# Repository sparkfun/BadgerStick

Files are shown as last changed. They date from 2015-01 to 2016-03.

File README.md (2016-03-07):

Interactive Badges
==================
 
 
 
 [*SparkFun BadgerHack *](https://learn.sparkfun.com/tutorials/badgerhack)
 
 These badges were designed as a soldering demo for the SparkFun booths at Maker Faire. 
 They were designed to teach the basics of PTH soldering, as well as to provide users with an Arduino platform they could take home and hack.
 
Please view the [BadgerHack tutorial](https://learn.sparkfun.com/tutorials/badgerhack) for more information on updating the firmware, and further experiments with your badge. 
 
 Repository Contents
-------------------

* **/badgerstick/avr** - Board definition files for Arduino.
* **/Documentation** - SoftwareSerial Baud Rate table
* **/Firmware** - Default firmware that ships on the BadgerStick
* **/Hardware** - All Eagle design files (.brd, .sch)
* **/Production** - Test bed files and production panel files

Documentation
--------------
* **[Library](https://github.com/sparkfun/SparkFun_LED_Array_8x7_Arduino_Library)** - Arduino library for the BadgerStick.
* **[Hookup Guide](https://learn.sparkfun.com/tutorials/badgerhack)** - Basic hookup guide for the BadgerStick. 
* **[SparkFun Fritzing repo](https://github.com/sparkfun/Fritzing_Parts)** - Fritzing diagrams for SparkFun products.
* **[SparkFun 3D Model repo](https://github.com/sparkfun/3D_Models)** - 3D models of SparkFun products. 
* **[SparkFun Graphical Datasheets](https://github.com/sparkfun/Graphical_Datasheets)** -Graphical Datasheets for various SparkFun products.

License Information
-------------------

This product is _**open source**_! 

Please review the LICENSE.md file for license information. 

If you have any questions or concerns on licensing, please contact techsupport@sparkfun.com.

Distributed as-is; no warranty is given.

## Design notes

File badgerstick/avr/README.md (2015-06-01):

Custom bootloader and board definition file

Version
-------

**v0.2**

Known Issues
------------

Getting Started
---------------

I want to upload Arduino sketches to my BadgerStick (which already has the bootloader).

* Copy the badgerstick directory to <Arduino folder>/hardware/
* Open the Arduino program
* BadgerStick should appear under Tools -> Board

I want to compile the BadgerStick bootloader.

* Copy ATmegaBOOT_168.c and the Makefile located in bootloaders/atmega to <Arduino folder>/hardware/arduino/bootloaders/atmega
* Open a command terminal
* Navigate to <Arduino folder>/hardware/arduino/bootloaders/atmega
* Enter the command: make

I want to burn the bootloader onto the BadgerStick.

* If you did not compile the bootloader, copy the ATmegaBOOT_168_atmega328_pro_4MHz.hex file in bootloaders/atmega to <Arduino folder>/hardware/arduino/bootloaders/atmega
* Follow the instructions at [http://arduino.cc/en/Tutorial/ArduinoISP](http://arduino.cc/en/Tutorial/ArduinoISP) to use an Arduino as a programmer for the BadgerStick
* Select "BadgerStick (3.3V, 4MHz)" when instructed to select the board "on which you want to burn the bootloader"
* Use the Tools -> Burn Bootloader option
* Wait for the bootloader to finish burning (you will get a notification in the Arduino program)

What Did You Do?
----------------

To create a custom board for the Arduino program, we created a new directory with hardware definitions.

To create a custom bootloader, we changed a few lines of code in ATmegaBOOT_168.c under "// Fix the EEWE bit definition..." in order to fix a compile error (EEPE not defined). We also changed the OPTIMIZE setting to -Os to reduce the size of the bootloader file. Finally, we added a new Make target under "# Added 4MHz version of the 328P" with new fuse settings to allow for lower voltage and 4MHz operation.

Version History
---------------

**v0.2**

* Created separate hardware directory to support Arduino IDE v1.6.3
* Changed upload speed to 250000

**v0.1**

* Initial prototype
* 4MHz with 1.8V brown-out detection Arduino bootloader created for ATmega 328P
* Custom board definition added to boards.txt for the BadgerStick

License
-------

All Arduino code is release under the Creative Commons Attribution Share-Alike license. For more information, see [http://arduino.cc/en/Main/FAQ](http://arduino.cc/en/Main/FAQ).

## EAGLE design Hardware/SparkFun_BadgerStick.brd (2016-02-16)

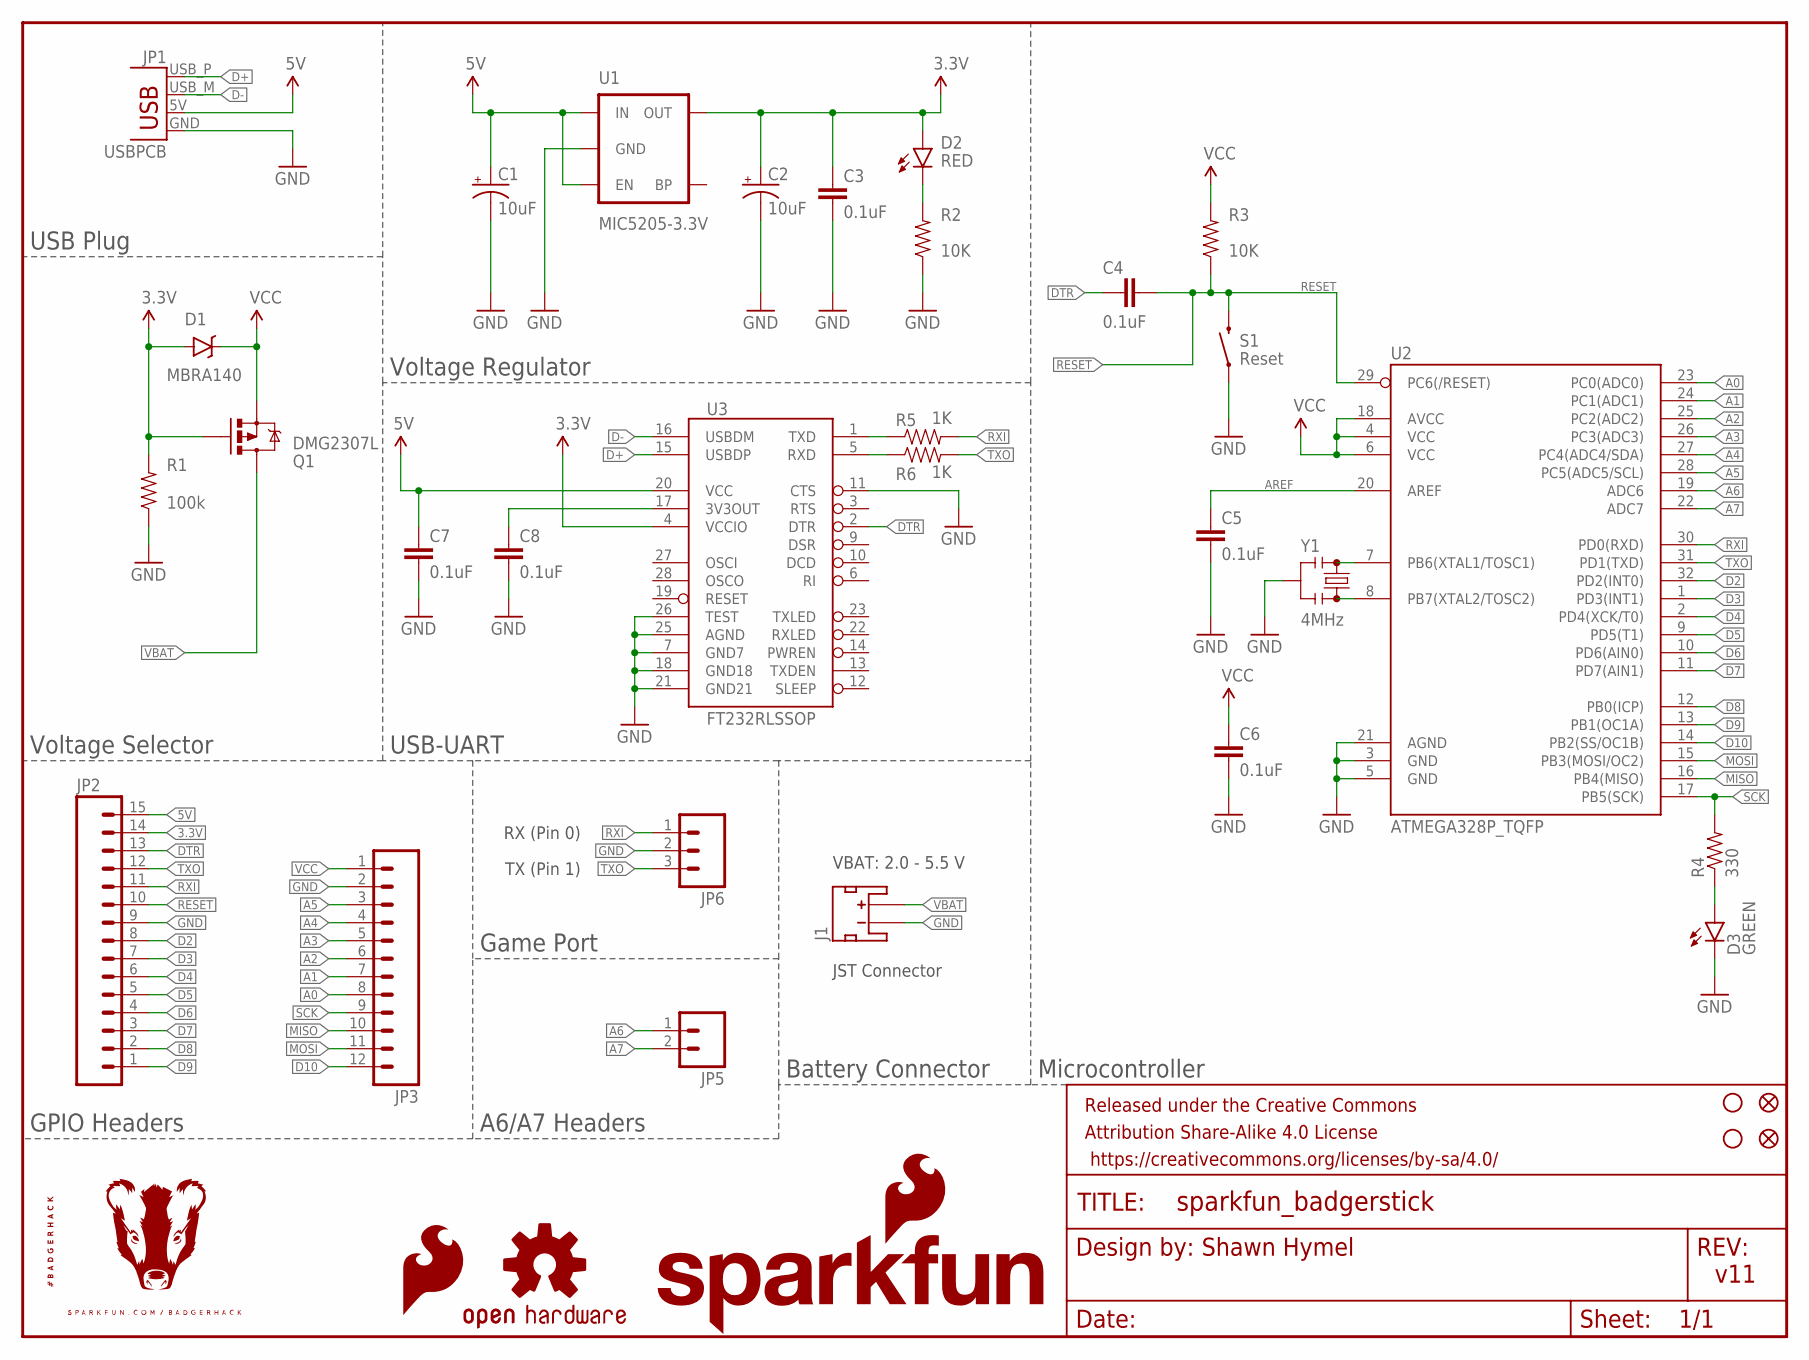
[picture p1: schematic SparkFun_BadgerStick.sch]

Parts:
C1, C2: 10uF; EIA3216
C3, C4, C5, C6, C7, C8: 0.1uF; 0603-CAP
D1: MBRA140; SMA-DIODE
D2: RED; LED-0603
D3: GREEN; LED-0603
FID1, FID2: FIDUCIAL1X2; FIDUCIAL-1X2
FRAME1: FRAME-LETTER; CREATIVE_COMMONS
J1: JST_2MM_MALE; JST-2-SMD
JP1: USBPCB; USB-A-PCB
JP2: M15LOCK_NO_SILK; 1X15_LOCK_NO_SILK
JP3: M12LOCK_NO_SILK; 1X12_LOCK_NO_SILK
JP5: M021X02_NO_SILK; 1X02_NO_SILK
JP6: M03LOCK Female; 1X03_LOCK_NO_SILK
LOGO1: SFE_LOGO_FLAME.1_INCH; SFE_LOGO_FLAME_.1
LOGO2: OSHW-LOGOS; OSHW-LOGO-S
Q1: DMG2307L; SOT23-3
R1: 100k; 0603-RES
R2, R3: 10K; 0603-RES
R4: 330; 0603-RES
R5, R6: 1K; 0603-RES
S1: SWITCH-MOMENTARY-2SMD-REDUNDANT; TACTILE-SWITCH-SMD
STANDOFF1, STANDOFF2: STAND-OFF
U1: MIC5205-3.3V; SOT23-5
U2: ATMEGA328P_TQFP; TQFP32-08
U3: FT232RLSSOP; SSOP28DB
U$1: SFE_LOGO_NAME_FLAME.1_INCH; SFE_LOGO_NAME_FLAME_.1
U$2: BADGERHACK_LOGODUMMY; DUMMY
Y1: 4MHz; RESONATOR-SMD_MED

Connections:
3.3V: C2.A (+), C3.1, D1.A, D2.A, JP2.14, Q1.1 (G), R1.2, U1.5 (OUT), U3.4 (VCCIO)
5V: C1.A (+), C7.1, JP1.5V (VBUS), JP2.15, U1.1 (IN), U1.3 (EN), U3.20 (VCC)
A0: JP3.8, U2.23 (PC0(ADC0))
A1: JP3.7, U2.24 (PC1(ADC1))
A2: JP3.6, U2.25 (PC2(ADC2))
A3: JP3.5, U2.26 (PC3(ADC3))
A4: JP3.4, U2.27 (PC4(ADC4/SDA))
A5: JP3.3, U2.28 (PC5(ADC5/SCL))
A6: JP5.1, U2.19 (ADC6)
A7: JP5.2, U2.22 (ADC7)
AREF: C5.1, U2.20 (AREF)
D2: JP2.8, U2.32 (PD2(INT0))
D3: JP2.7, U2.1 (PD3(INT1))
D4: JP2.6, U2.2 (PD4(XCK/T0))
D5: JP2.5, U2.9 (PD5(T1))
D6: JP2.4, U2.10 (PD6(AIN0))
D7: JP2.3, U2.11 (PD7(AIN1))
D8: JP2.2, U2.12 (PB0(ICP))
D9: JP2.1, U2.13 (PB1(OC1A))
D10: JP3.12, U2.14 (PB2(SS/OC1B))
D+: JP1.USB_P (D+), U3.15 (USBDP)
D-: JP1.USB_M (D-), U3.16 (USBDM)
DTR: C4.1, JP2.13, U3.2 (DTR)
GND: C1.C (-), C2.C (-), C3.2, C5.2, C6.2, C7.2, C8.2, D3.C, J1.1 (-), JP1.GND, JP2.9, JP3.2, JP6.2, R1.1, R2.1, S1.1, S1.2 (1), U1.2 (GND), U2.3 (GND), U2.5 (GND), U2.21 (AGND), U3.7 (GND7), U3.11 (CTS), U3.18 (GND18), U3.21 (GND21), U3.25 (AGND), U3.26 (TEST), Y1.2
MISO: JP3.10, U2.16 (PB4(MISO))
MOSI: JP3.11, U2.15 (PB3(MOSI/OC2))
unnamed: D3.A, R4.1
unnamed: C8.1, U3.17 (3V3OUT)
unnamed: R5.1, U3.1 (TXD)
unnamed: D2.C, R2.2
unnamed: U2.7 (PB6(XTAL1/TOSC1)), Y1.1
unnamed: U2.8 (PB7(XTAL2/TOSC2)), Y1.3
unnamed: R6.1, U3.5 (RXD)
RESET: C4.2, JP2.10, R3.1, S1.3 (2), S1.4 (2), U2.29 (PC6(/RESET))
RXI: JP2.11, JP6.1, R5.2, U2.30 (PD0(RXD))
SCK: JP3.9, R4.2, U2.17 (PB5(SCK))
TXO: JP2.12, JP6.3, R6.2, U2.31 (PD1(TXD))
VBAT: J1.2 (+), Q1.3 (D)
VCC: C6.1, D1.C, JP3.1, Q1.2 (S), R3.2, U2.4 (VCC), U2.6 (VCC), U2.18 (AVCC)

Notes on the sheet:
RX (Pin 0)
TX (Pin 1)
USB Plug
Voltage Selector
GPIO Headers
A6/A7 Headers
Game Port
USB-UART
Voltage Regulator
Microcontroller
Battery Connector
VBAT: 2.0 - 5.5 V
JST Connector

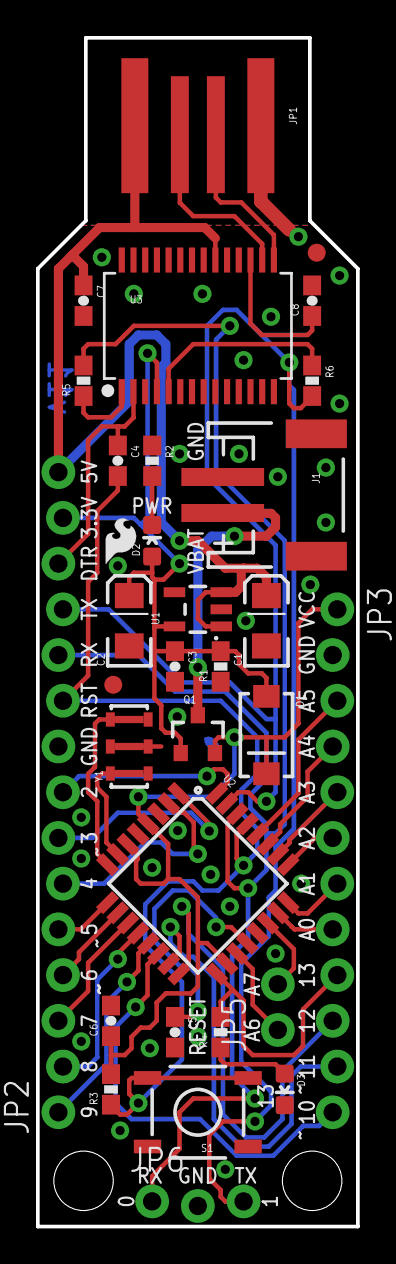
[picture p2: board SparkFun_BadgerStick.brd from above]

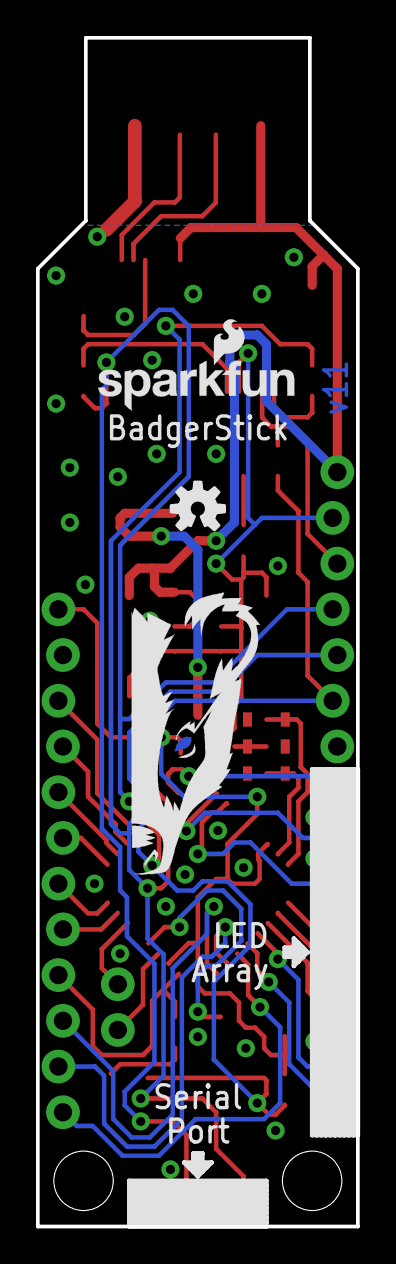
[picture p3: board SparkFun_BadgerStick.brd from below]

Board: 2 copper layers, 17.8 x 66.0 mm, 39 parts (3 on the bottom side), 39 nets.

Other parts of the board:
U$3: HALF_BADGER

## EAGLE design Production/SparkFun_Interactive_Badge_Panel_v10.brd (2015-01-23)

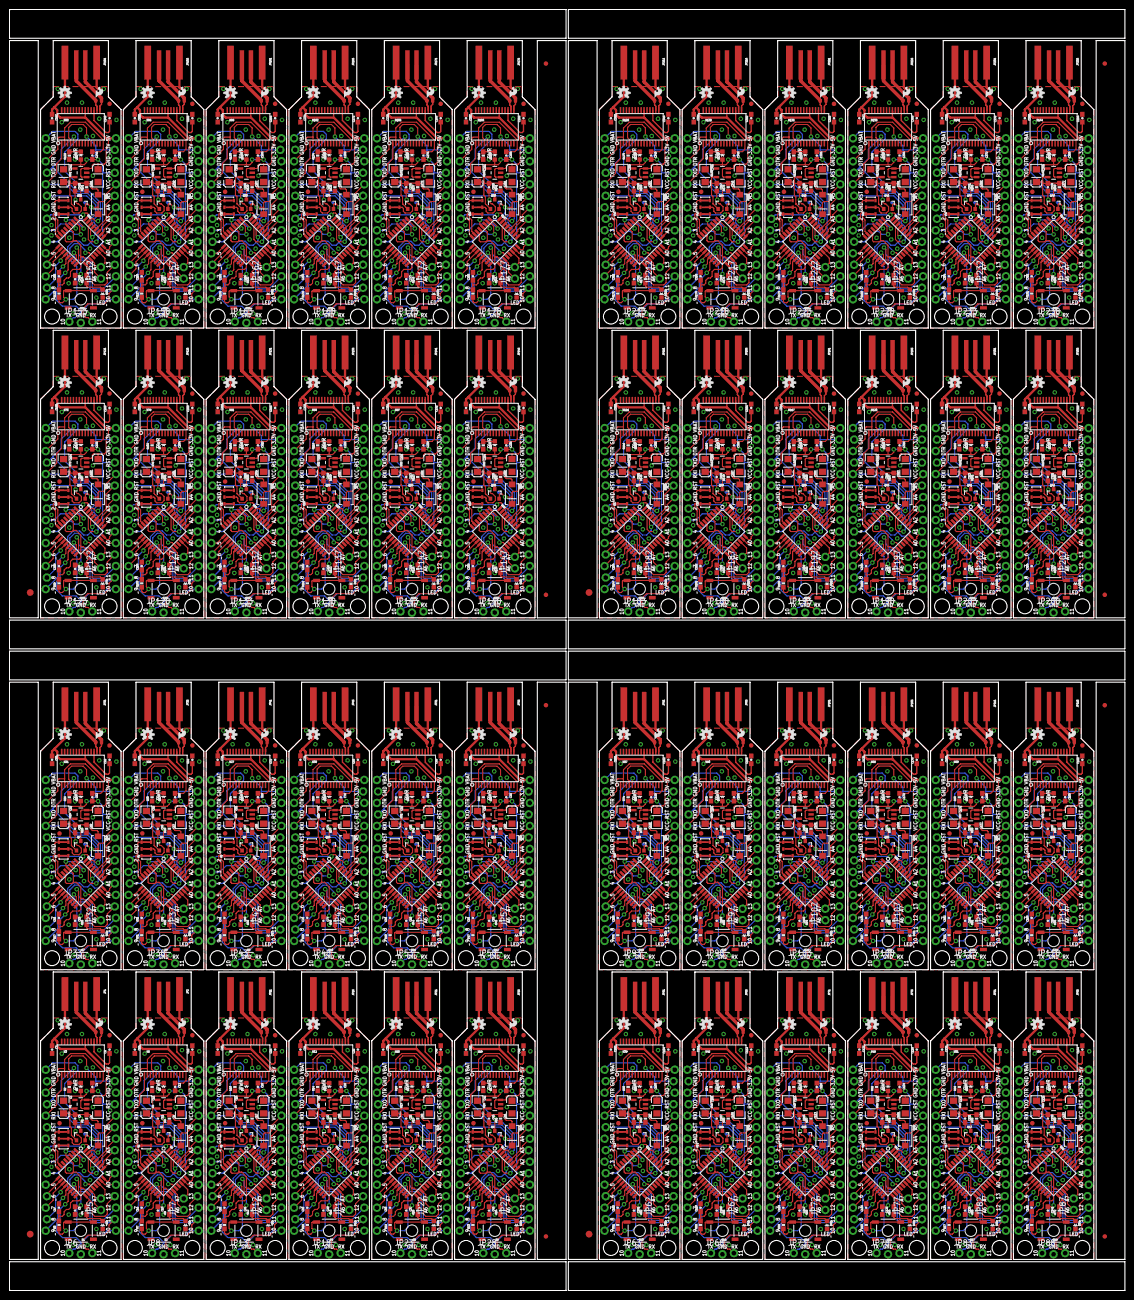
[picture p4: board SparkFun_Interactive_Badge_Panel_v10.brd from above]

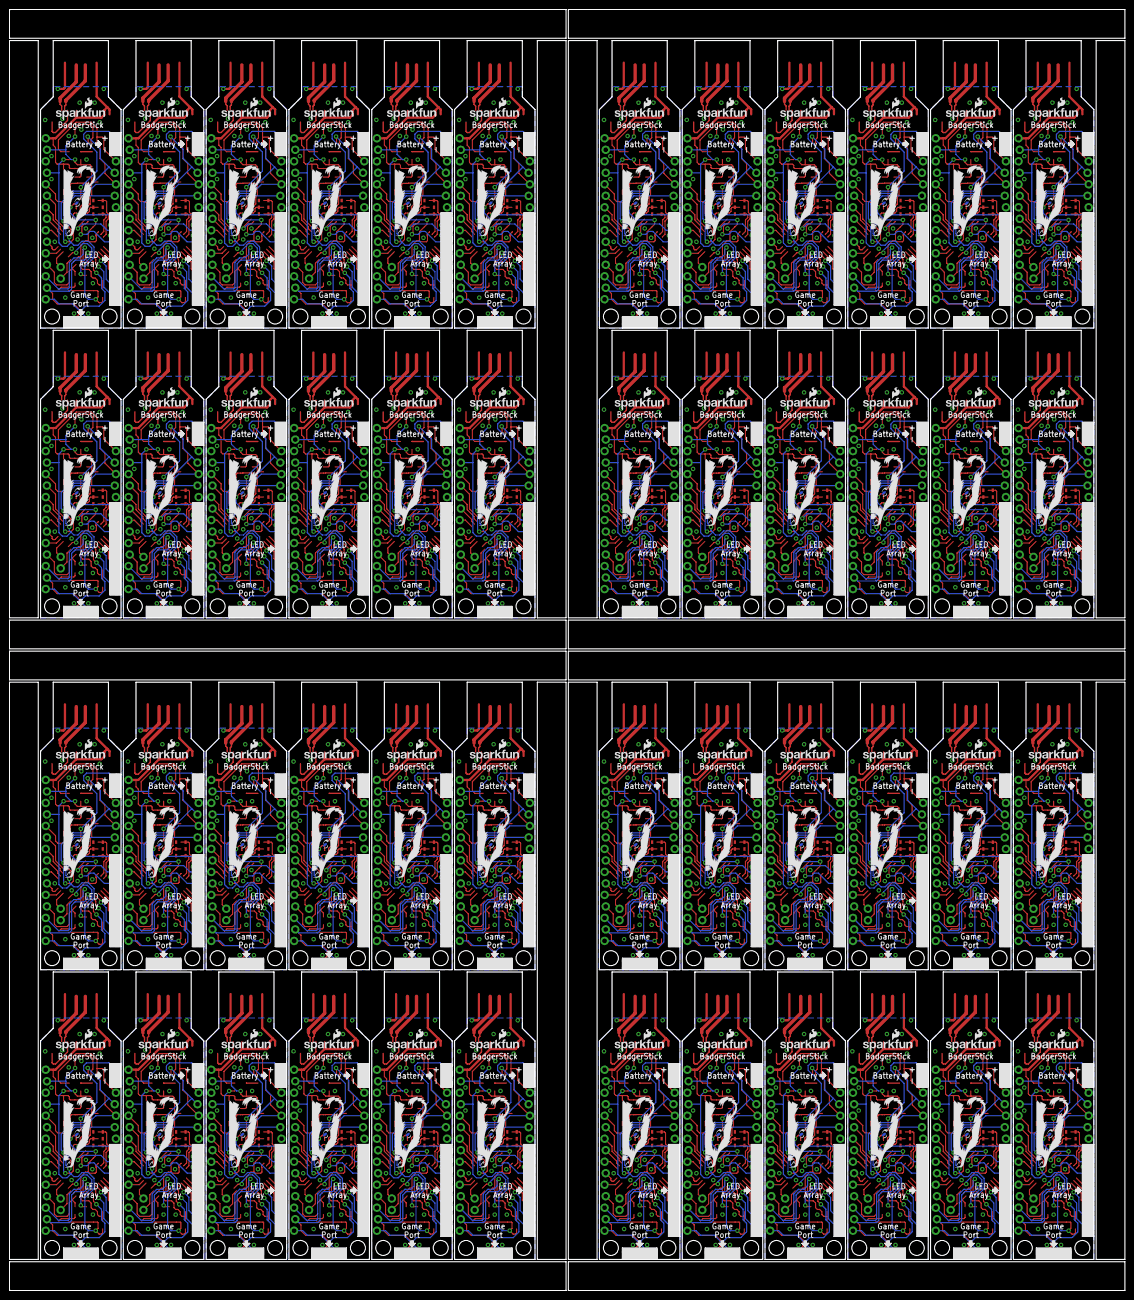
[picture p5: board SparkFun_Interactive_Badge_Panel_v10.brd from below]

Board: 2 copper layers, 246.4 x 283.0 mm, 1644 parts (96 on the bottom side), 1776 nets.

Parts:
C1, C2, C9, C10, C17, C18, C25, C26, C33, C34, C41, C42, C49, C50, C57, C58, C65, C66, C73, C74, C81, C82, C89, C90, C97, C98, C105, C106, C113, C114, C121, C122, C129, C130, C137, C138, C145, C146, C153, C154, C161, C162, C169, C170, C177, C178, C185, C186, C193, C194, C201, C202, C209, C210, C217, C218, C225, C226, C233, C234, C241, C242, C249, C250, C257, C258, C265, C266, C273, C274, C281, C282, C289, C290, C297, C298, C305, C306, C313, C314, C321, C322, C329, C330, C337, C338, C345, C346, C353, C354, C361, C362, C369, C370, C377, C378: 10uF; EIA3216
C3, C4, C5, C6, C7, C8, C11, C12, C13, C14, C15, C16, C19, C20, C21, C22, C23, C24, C27, C28, C29, C30, C31, C32, C35, C36, C37, C38, C39, C40, C43, C44, C45, C46, C47, C48, C51, C52, C53, C54, C55, C56, C59, C60, C61, C62, C63, C64, C67, C68, C69, C70, C71, C72, C75, C76, C77, C78, C79, C80, C83, C84, C85, C86, C87, C88, C91, C92, C93, C94, C95, C96, C99, C100, C101, C102, C103, C104, C107, C108, C109, C110, C111, C112, C115, C116, C117, C118, C119, C120, C123, C124, C125, C126, C127, C128, C131, C132, C133, C134, C135, C136, C139, C140, C141, C142, C143, C144, C147, C148, C149, C150, C151, C152, C155, C156, C157, C158, C159, C160, C163, C164, C165, C166, C167, C168, C171, C172, C173, C174, C175, C176, C179, C180, C181, C182, C183, C184, C187, C188, C189, C190, C191, C192, C195, C196, C197, C198, C199, C200, C203, C204, C205, C206, C207, C208, C211, C212, C213, C214, C215, C216, C219, C220, C221, C222, C223, C224, C227, C228, C229, C230, C231, C232, C235, C236, C237, C238, C239, C240, C243, C244, C245, C246, C247, C248, C251, C252, C253, C254, C255, C256, C259, C260, C261, C262, C263, C264, C267, C268, C269, C270, C271, C272, C275, C276, C277, C278, C279, C280, C283, C284, C285, C286, C287, C288, C291, C292, C293, C294, C295, C296, C299, C300, C301, C302, C303, C304, C307, C308, C309, C310, C311, C312, C315, C316, C317, C318, C319, C320, C323, C324, C325, C326, C327, C328, C331, C332, C333, C334, C335, C336, C339, C340, C341, C342, C343, C344, C347, C348, C349, C350, C351, C352, C355, C356, C357, C358, C359, C360, C363, C364, C365, C366, C367, C368, C371, C372, C373, C374, C375, C376, C379, C380, C381, C382, C383, C384: 0.1uF; 0603-CAP
D1, D4, D7, D10, D13, D16, D19, D22, D25, D28, D31, D34, D37, D40, D43, D46, D49, D52, D55, D58, D61, D64, D67, D70, D73, D76, D79, D82, D85, D88, D91, D94, D97, D100, D103, D106, D109, D112, D115, D118, D121, D124, D127, D130, D133, D136, D139, D142: MBRA140; SMA-DIODE
D2, D5, D8, D11, D14, D17, D20, D23, D26, D29, D32, D35, D38, D41, D44, D47, D50, D53, D56, D59, D62, D65, D68, D71, D74, D77, D80, D83, D86, D89, D92, D95, D98, D101, D104, D107, D110, D113, D116, D119, D122, D125, D128, D131, D134, D137, D140, D143: RED; LED-0603
D3, D6, D9, D12, D15, D18, D21, D24, D27, D30, D33, D36, D39, D42, D45, D48, D51, D54, D57, D60, D63, D66, D69, D72, D75, D78, D81, D84, D87, D90, D93, D96, D99, D102, D105, D108, D111, D114, D117, D120, D123, D126, D129, D132, D135, D138, D141, D144: GREEN; LED-0603
E$1, E$6, E$9, E$12: FIDUCIAL-1.5X3
E$2, E$3, E$4, E$5, E$7, E$8, E$10, E$11: FIDUCIAL-1X2
FID1, FID2, FID3, FID4, FID5, FID6, FID7, FID8, FID9, FID10, FID11, FID12, FID13, FID14, FID15, FID16, FID17, FID18, FID19, FID20, FID21, FID22, FID23, FID24, FID25, FID26, FID27, FID28, FID29, FID30, FID31, FID32, FID33, FID34, FID35, FID36, FID37, FID38, FID39, FID40, FID41, FID42, FID43, FID44, FID45, FID46, FID47, FID48, FID49, FID50, FID51, FID52, FID53, FID54, FID55, FID56, FID57, FID58, FID59, FID60, FID61, FID62, FID63, FID64, FID65, FID66, FID67, FID68, FID69, FID70, FID71, FID72, FID73, FID74, FID75, FID76, FID77, FID78, FID79, FID80, FID81, FID82, FID83, FID84, FID85, FID86, FID87, FID88, FID89, FID90, FID91, FID92, FID93, FID94, FID95, FID96: FIDUCIAL1X2; FIDUCIAL-1X2
JP1, JP2, JP11, JP16, JP21, JP26, JP31, JP36, JP41, JP46, JP51, JP56, JP61, JP66, JP71, JP76, JP81, JP86, JP91, JP96, JP101, JP106, JP111, JP116, JP121, JP126, JP131, JP136, JP141, JP146, JP151, JP156, JP161, JP166, JP171, JP176, JP181, JP186, JP191, JP196, JP201, JP206, JP211, JP216, JP221, JP226, JP231, JP236: USBPCB; USB-A-PCB
JP3, JP4, JP9, JP10, JP14, JP15, JP19, JP20, JP24, JP25, JP29, JP30, JP34, JP35, JP39, JP40, JP44, JP45, JP49, JP50, JP54, JP55, JP59, JP60, JP64, JP65, JP69, JP70, JP74, JP75, JP79, JP80, JP84, JP85, JP89, JP90, JP94, JP95, JP99, JP100, JP104, JP105, JP109, JP110, JP114, JP115, JP119, JP120, JP124, JP125, JP129, JP130, JP134, JP135, JP139, JP140, JP144, JP145, JP149, JP150, JP154, JP155, JP159, JP160, JP164, JP165, JP169, JP170, JP174, JP175, JP179, JP180, JP184, JP185, JP189, JP190, JP194, JP195, JP199, JP200, JP204, JP205, JP209, JP210, JP214, JP215, JP219, JP220, JP224, JP225, JP229, JP230, JP234, JP235, JP239, JP240: M15LOCK_NO_SILK; 1X15_LOCK_NO_SILK
JP5, JP7, JP12, JP17, JP22, JP27, JP32, JP37, JP42, JP47, JP52, JP57, JP62, JP67, JP72, JP77, JP82, JP87, JP92, JP97, JP102, JP107, JP112, JP117, JP122, JP127, JP132, JP137, JP142, JP147, JP152, JP157, JP162, JP167, JP172, JP177, JP182, JP187, JP192, JP197, JP202, JP207, JP212, JP217, JP222, JP227, JP232, JP237: M021X02_NO_SILK; 1X02_NO_SILK
JP6, JP8, JP13, JP18, JP23, JP28, JP33, JP38, JP43, JP48, JP53, JP58, JP63, JP68, JP73, JP78, JP83, JP88, JP93, JP98, JP103, JP108, JP113, JP118, JP123, JP128, JP133, JP138, JP143, JP148, JP153, JP158, JP163, JP168, JP173, JP178, JP183, JP188, JP193, JP198, JP203, JP208, JP213, JP218, JP223, JP228, JP233, JP238: M03LOCK Female; 1X03_LOCK_NO_SILK
LOGO1, LOGO3, LOGO5, LOGO7, LOGO9, LOGO11, LOGO13, LOGO15, LOGO17, LOGO19, LOGO21, LOGO23, LOGO25, LOGO27, LOGO29, LOGO31, LOGO33, LOGO35, LOGO37, LOGO39, LOGO41, LOGO43, LOGO45, LOGO47, LOGO49, LOGO51, LOGO53, LOGO55, LOGO57, LOGO59, LOGO61, LOGO63, LOGO65, LOGO67, LOGO69, LOGO71, LOGO73, LOGO75, LOGO77, LOGO79, LOGO81, LOGO83, LOGO85, LOGO87, LOGO89, LOGO91, LOGO93, LOGO95: SFE_LOGO_FLAME.1_INCH; SFE_LOGO_FLAME_.1
LOGO2, LOGO4, LOGO6, LOGO8, LOGO10, LOGO12, LOGO14, LOGO16, LOGO18, LOGO20, LOGO22, LOGO24, LOGO26, LOGO28, LOGO30, LOGO32, LOGO34, LOGO36, LOGO38, LOGO40, LOGO42, LOGO44, LOGO46, LOGO48, LOGO50, LOGO52, LOGO54, LOGO56, LOGO58, LOGO60, LOGO62, LOGO64, LOGO66, LOGO68, LOGO70, LOGO72, LOGO74, LOGO76, LOGO78, LOGO80, LOGO82, LOGO84, LOGO86, LOGO88, LOGO90, LOGO92, LOGO94, LOGO96: OSHW-LOGOS; OSHW-LOGO-S
Q1, Q2, Q3, Q4, Q5, Q6, Q7, Q8, Q9, Q10, Q11, Q12, Q13, Q14, Q15, Q16, Q17, Q18, Q19, Q20, Q21, Q22, Q23, Q24, Q25, Q26, Q27, Q28, Q29, Q30, Q31, Q32, Q33, Q34, Q35, Q36, Q37, Q38, Q39, Q40, Q41, Q42, Q43, Q44, Q45, Q46, Q47, Q48: DMG2307L; SOT23-3
R1, R5, R9, R13, R17, R21, R25, R29, R33, R37, R41, R45, R49, R53, R57, R61, R65, R69, R73, R77, R81, R85, R89, R93, R97, R101, R105, R109, R113, R117, R121, R125, R129, R133, R137, R141, R145, R149, R153, R157, R161, R165, R169, R173, R177, R181, R185, R189: 100k; 0603-RES
R2, R3, R6, R7, R10, R11, R14, R15, R18, R19, R22, R23, R26, R27, R30, R31, R34, R35, R38, R39, R42, R43, R46, R47, R50, R51, R54, R55, R58, R59, R62, R63, R66, R67, R70, R71, R74, R75, R78, R79, R82, R83, R86, R87, R90, R91, R94, R95, R98, R99, R102, R103, R106, R107, R110, R111, R114, R115, R118, R119, R122, R123, R126, R127, R130, R131, R134, R135, R138, R139, R142, R143, R146, R147, R150, R151, R154, R155, R158, R159, R162, R163, R166, R167, R170, R171, R174, R175, R178, R179, R182, R183, R186, R187, R190, R191: 10K; 0603-RES
R4, R8, R12, R16, R20, R24, R28, R32, R36, R40, R44, R48, R52, R56, R60, R64, R68, R72, R76, R80, R84, R88, R92, R96, R100, R104, R108, R112, R116, R120, R124, R128, R132, R136, R140, R144, R148, R152, R156, R160, R164, R168, R172, R176, R180, R184, R188, R192: 330; 0603-RES
S1, S2, S3, S4, S5, S6, S7, S8, S9, S10, S11, S12, S13, S14, S15, S16, S17, S18, S19, S20, S21, S22, S23, S24, S25, S26, S27, S28, S29, S30, S31, S32, S33, S34, S35, S36, S37, S38, S39, S40, S41, S42, S43, S44, S45, S46, S47, S48: SWITCH-MOMENTARY-2SMD-REDUNDANT; TACTILE-SWITCH-SMD
STANDOFF1, STANDOFF2, STANDOFF3, STANDOFF4, STANDOFF5, STANDOFF6, STANDOFF7, STANDOFF8, STANDOFF9, STANDOFF10, STANDOFF11, STANDOFF12, STANDOFF13, STANDOFF14, STANDOFF15, STANDOFF16, STANDOFF17, STANDOFF18, STANDOFF19, STANDOFF20, STANDOFF21, STANDOFF22, STANDOFF23, STANDOFF24, STANDOFF25, STANDOFF26, STANDOFF27, STANDOFF28, STANDOFF29, STANDOFF30, STANDOFF31, STANDOFF32, STANDOFF33, STANDOFF34, STANDOFF35, STANDOFF36, STANDOFF37, STANDOFF38, STANDOFF39, STANDOFF40, STANDOFF41, STANDOFF42, STANDOFF43, STANDOFF44, STANDOFF45, STANDOFF46, STANDOFF47, STANDOFF48, STANDOFF49, STANDOFF50, STANDOFF51, STANDOFF52, STANDOFF53, STANDOFF54, STANDOFF55, STANDOFF56, STANDOFF57, STANDOFF58, STANDOFF59, STANDOFF60, STANDOFF61, STANDOFF62, STANDOFF63, STANDOFF64, STANDOFF65, STANDOFF66, STANDOFF67, STANDOFF68, STANDOFF69, STANDOFF70, STANDOFF71, STANDOFF72, STANDOFF73, STANDOFF74, STANDOFF75, STANDOFF76, STANDOFF77, STANDOFF78, STANDOFF79, STANDOFF80, STANDOFF81, STANDOFF82, STANDOFF83, STANDOFF84, STANDOFF85, STANDOFF86, STANDOFF87, STANDOFF88, STANDOFF89, STANDOFF90, STANDOFF91, STANDOFF92, STANDOFF93, STANDOFF94, STANDOFF95, STANDOFF96: STAND-OFF
U1, U4, U7, U10, U13, U16, U19, U22, U25, U28, U31, U34, U37, U40, U43, U46, U49, U52, U55, U58, U61, U64, U67, U70, U73, U76, U79, U82, U85, U88, U91, U94, U97, U100, U103, U106, U109, U112, U115, U118, U121, U124, U127, U130, U133, U136, U139, U142: MIC5205-3.3V; SOT23-5
U2, U5, U8, U11, U14, U17, U20, U23, U26, U29, U32, U35, U38, U41, U44, U47, U50, U53, U56, U59, U62, U65, U68, U71, U74, U77, U80, U83, U86, U89, U92, U95, U98, U101, U104, U107, U110, U113, U116, U119, U122, U125, U128, U131, U134, U137, U140, U143: ATMEGA328P; TQFP32-08
U3, U6, U9, U12, U15, U18, U21, U24, U27, U30, U33, U36, U39, U42, U45, U48, U51, U54, U57, U60, U63, U66, U69, U72, U75, U78, U81, U84, U87, U90, U93, U96, U99, U102, U105, U108, U111, U114, U117, U120, U123, U126, U129, U132, U135, U138, U141, U144: CY7C65213; SSOP28DB
U$1, U$2, U$5, U$7, U$9, U$11, U$13, U$15, U$17, U$19, U$21, U$23, U$25, U$27, U$29, U$31, U$33, U$35, U$37, U$39, U$41, U$43, U$45, U$47, U$49, U$51, U$53, U$55, U$57, U$59, U$61, U$63, U$65, U$67, U$69, U$71, U$73, U$75, U$77, U$79, U$81, U$83, U$85, U$87, U$89, U$91, U$93, U$95: SFE_LOGO_NAME_FLAME.1_INCH; SFE_LOGO_NAME_FLAME_.1
U$3, U$4, U$6, U$8, U$10, U$12, U$14, U$16, U$18, U$20, U$22, U$24, U$26, U$28, U$30, U$32, U$34, U$36, U$38, U$40, U$42, U$44, U$46, U$48, U$50, U$52, U$54, U$56, U$58, U$60, U$62, U$64, U$66, U$68, U$70, U$72, U$74, U$76, U$78, U$80, U$82, U$84, U$86, U$88, U$90, U$92, U$94, U$96: HALF_BADGER
Y1, Y2, Y3, Y4, Y5, Y6, Y7, Y8, Y9, Y10, Y11, Y12, Y13, Y14, Y15, Y16, Y17, Y18, Y19, Y20, Y21, Y22, Y23, Y24, Y25, Y26, Y27, Y28, Y29, Y30, Y31, Y32, Y33, Y34, Y35, Y36, Y37, Y38, Y39, Y40, Y41, Y42, Y43, Y44, Y45, Y46, Y47, Y48: 4MHz; RESONATOR-SMD_MED

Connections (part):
3.3V: C2.A, C3.1, D1.A, D2.A, JP4.2, Q1.1, R1.2, U1.5, U3.4
3.3V1: C10.A, C11.1, D4.A, D5.A, JP9.2, Q2.1, R5.2, U4.5, U6.4
3.3V2: C18.A, C19.1, D7.A, D8.A, JP14.2, Q3.1, R9.2, U7.5, U9.4
3.3V3: C26.A, C27.1, D10.A, D11.A, JP19.2, Q4.1, R13.2, U10.5, U12.4
3.3V4: C34.A, C35.1, D13.A, D14.A, JP24.2, Q5.1, R17.2, U13.5, U15.4
3.3V5: C42.A, C43.1, D16.A, D17.A, JP29.2, Q6.1, R21.2, U16.5, U18.4
3.3V6: C50.A, C51.1, D19.A, D20.A, JP34.2, Q7.1, R25.2, U19.5, U21.4
3.3V7: C58.A, C59.1, D22.A, D23.A, JP39.2, Q8.1, R29.2, U22.5, U24.4
3.3V8: C66.A, C67.1, D25.A, D26.A, JP44.2, Q9.1, R33.2, U25.5, U27.4
3.3V9: C74.A, C75.1, D28.A, D29.A, JP49.2, Q10.1, R37.2, U28.5, U30.4
3.3V10: C82.A, C83.1, D31.A, D32.A, JP54.2, Q11.1, R41.2, U31.5, U33.4
3.3V11: C90.A, C91.1, D34.A, D35.A, JP59.2, Q12.1, R45.2, U34.5, U36.4
3.3V12: C98.A, C99.1, D37.A, D38.A, JP64.2, Q13.1, R49.2, U37.5, U39.4
3.3V13: C106.A, C107.1, D40.A, D41.A, JP69.2, Q14.1, R53.2, U40.5, U42.4
3.3V14: C114.A, C115.1, D43.A, D44.A, JP74.2, Q15.1, R57.2, U43.5, U45.4
3.3V15: C122.A, C123.1, D46.A, D47.A, JP79.2, Q16.1, R61.2, U46.5, U48.4
3.3V16: C130.A, C131.1, D49.A, D50.A, JP84.2, Q17.1, R65.2, U49.5, U51.4
3.3V17: C138.A, C139.1, D52.A, D53.A, JP89.2, Q18.1, R69.2, U52.5, U54.4
3.3V18: C146.A, C147.1, D55.A, D56.A, JP94.2, Q19.1, R73.2, U55.5, U57.4
3.3V19: C154.A, C155.1, D58.A, D59.A, JP99.2, Q20.1, R77.2, U58.5, U60.4
3.3V20: C162.A, C163.1, D61.A, D62.A, JP104.2, Q21.1, R81.2, U61.5, U63.4
3.3V21: C170.A, C171.1, D64.A, D65.A, JP109.2, Q22.1, R85.2, U64.5, U66.4
3.3V22: C178.A, C179.1, D67.A, D68.A, JP114.2, Q23.1, R89.2, U67.5, U69.4
3.3V23: C186.A, C187.1, D70.A, D71.A, JP119.2, Q24.1, R93.2, U70.5, U72.4
3.3V24: C194.A, C195.1, D73.A, D74.A, JP124.2, Q25.1, R97.2, U73.5, U75.4
3.3V25: C202.A, C203.1, D76.A, D77.A, JP129.2, Q26.1, R101.2, U76.5, U78.4
3.3V26: C210.A, C211.1, D79.A, D80.A, JP134.2, Q27.1, R105.2, U79.5, U81.4
3.3V27: C218.A, C219.1, D82.A, D83.A, JP139.2, Q28.1, R109.2, U82.5, U84.4
3.3V28: C226.A, C227.1, D85.A, D86.A, JP144.2, Q29.1, R113.2, U85.5, U87.4
3.3V29: C234.A, C235.1, D88.A, D89.A, JP149.2, Q30.1, R117.2, U88.5, U90.4
3.3V30: C242.A, C243.1, D91.A, D92.A, JP154.2, Q31.1, R121.2, U91.5, U93.4
3.3V31: C250.A, C251.1, D94.A, D95.A, JP159.2, Q32.1, R125.2, U94.5, U96.4
3.3V32: C258.A, C259.1, D97.A, D98.A, JP164.2, Q33.1, R129.2, U97.5, U99.4
3.3V33: C266.A, C267.1, D100.A, D101.A, JP169.2, Q34.1, R133.2, U100.5, U102.4
3.3V34: C274.A, C275.1, D103.A, D104.A, JP174.2, Q35.1, R137.2, U103.5, U105.4
3.3V35: C282.A, C283.1, D106.A, D107.A, JP179.2, Q36.1, R141.2, U106.5, U108.4
3.3V36: C290.A, C291.1, D109.A, D110.A, JP184.2, Q37.1, R145.2, U109.5, U111.4
3.3V37: C298.A, C299.1, D112.A, D113.A, JP189.2, Q38.1, R149.2, U112.5, U114.4
3.3V38: C306.A, C307.1, D115.A, D116.A, JP194.2, Q39.1, R153.2, U115.5, U117.4
3.3V39: C314.A, C315.1, D118.A, D119.A, JP199.2, Q40.1, R157.2, U118.5, U120.4
3.3V40: C322.A, C323.1, D121.A, D122.A, JP204.2, Q41.1, R161.2, U121.5, U123.4
3.3V41: C330.A, C331.1, D124.A, D125.A, JP209.2, Q42.1, R165.2, U124.5, U126.4
3.3V42: C338.A, C339.1, D127.A, D128.A, JP214.2, Q43.1, R169.2, U127.5, U129.4
3.3V43: C346.A, C347.1, D130.A, D131.A, JP219.2, Q44.1, R173.2, U130.5, U132.4
3.3V44: C354.A, C355.1, D133.A, D134.A, JP224.2, Q45.1, R177.2, U133.5, U135.4
3.3V45: C362.A, C363.1, D136.A, D137.A, JP229.2, Q46.1, R181.2, U136.5, U138.4
3.3V46: C370.A, C371.1, D139.A, D140.A, JP234.2, Q47.1, R185.2, U139.5, U141.4
3.3V47: C378.A, C379.1, D142.A, D143.A, JP239.2, Q48.1, R189.2, U142.5, U144.4
5V: C1.A, C7.1, JP1.5V, JP4.1, U1.1, U1.3, U3.20
5V1: C9.A, C15.1, JP2.5V, JP9.1, U4.1, U4.3, U6.20
5V2: C17.A, C23.1, JP11.5V, JP14.1, U7.1, U7.3, U9.20
5V3: C25.A, C31.1, JP16.5V, JP19.1, U10.1, U10.3, U12.20
5V4: C33.A, C39.1, JP21.5V, JP24.1, U13.1, U13.3, U15.20
5V5: C41.A, C47.1, JP26.5V, JP29.1, U16.1, U16.3, U18.20
5V6: C49.A, C55.1, JP31.5V, JP34.1, U19.1, U19.3, U21.20
5V7: C57.A, C63.1, JP36.5V, JP39.1, U22.1, U22.3, U24.20
5V8: C65.A, C71.1, JP41.5V, JP44.1, U25.1, U25.3, U27.20
5V9: C73.A, C79.1, JP46.5V, JP49.1, U28.1, U28.3, U30.20
5V10: C81.A, C87.1, JP51.5V, JP54.1, U31.1, U31.3, U33.20
5V11: C89.A, C95.1, JP56.5V, JP59.1, U34.1, U34.3, U36.20
5V12: C97.A, C103.1, JP61.5V, JP64.1, U37.1, U37.3, U39.20
5V13: C105.A, C111.1, JP66.5V, JP69.1, U40.1, U40.3, U42.20
5V14: C113.A, C119.1, JP71.5V, JP74.1, U43.1, U43.3, U45.20
5V15: C121.A, C127.1, JP76.5V, JP79.1, U46.1, U46.3, U48.20
5V16: C129.A, C135.1, JP81.5V, JP84.1, U49.1, U49.3, U51.20
5V17: C137.A, C143.1, JP86.5V, JP89.1, U52.1, U52.3, U54.20
5V18: C145.A, C151.1, JP91.5V, JP94.1, U55.1, U55.3, U57.20
5V19: C153.A, C159.1, JP96.5V, JP99.1, U58.1, U58.3, U60.20
5V20: C161.A, C167.1, JP101.5V, JP104.1, U61.1, U61.3, U63.20
5V21: C169.A, C175.1, JP106.5V, JP109.1, U64.1, U64.3, U66.20
5V22: C177.A, C183.1, JP111.5V, JP114.1, U67.1, U67.3, U69.20
5V23: C185.A, C191.1, JP116.5V, JP119.1, U70.1, U70.3, U72.20
5V24: C193.A, C199.1, JP121.5V, JP124.1, U73.1, U73.3, U75.20
5V25: C201.A, C207.1, JP126.5V, JP129.1, U76.1, U76.3, U78.20
5V26: C209.A, C215.1, JP131.5V, JP134.1, U79.1, U79.3, U81.20
5V27: C217.A, C223.1, JP136.5V, JP139.1, U82.1, U82.3, U84.20
5V28: C225.A, C231.1, JP141.5V, JP144.1, U85.1, U85.3, U87.20
5V29: C233.A, C239.1, JP146.5V, JP149.1, U88.1, U88.3, U90.20
5V30: C241.A, C247.1, JP151.5V, JP154.1, U91.1, U91.3, U93.20
5V31: C249.A, C255.1, JP156.5V, JP159.1, U94.1, U94.3, U96.20
5V32: C257.A, C263.1, JP161.5V, JP164.1, U97.1, U97.3, U99.20
5V33: C265.A, C271.1, JP166.5V, JP169.1, U100.1, U100.3, U102.20
5V34: C273.A, C279.1, JP171.5V, JP174.1, U103.1, U103.3, U105.20
5V35: C281.A, C287.1, JP176.5V, JP179.1, U106.1, U106.3, U108.20
5V36: C289.A, C295.1, JP181.5V, JP184.1, U109.1, U109.3, U111.20
5V37: C297.A, C303.1, JP186.5V, JP189.1, U112.1, U112.3, U114.20
5V38: C305.A, C311.1, JP191.5V, JP194.1, U115.1, U115.3, U117.20
5V39: C313.A, C319.1, JP196.5V, JP199.1, U118.1, U118.3, U120.20
5V40: C321.A, C327.1, JP201.5V, JP204.1, U121.1, U121.3, U123.20
5V41: C329.A, C335.1, JP206.5V, JP209.1, U124.1, U124.3, U126.20
5V42: C337.A, C343.1, JP211.5V, JP214.1, U127.1, U127.3, U129.20
5V43: C345.A, C351.1, JP216.5V, JP219.1, U130.1, U130.3, U132.20
5V44: C353.A, C359.1, JP221.5V, JP224.1, U133.1, U133.3, U135.20
5V45: C361.A, C367.1, JP226.5V, JP229.1, U136.1, U136.3, U138.20
5V46: C369.A, C375.1, JP231.5V, JP234.1, U139.1, U139.3, U141.20
5V47: C377.A, C383.1, JP236.5V, JP239.1, U142.1, U142.3, U144.20
A0: JP4.11, U2.23
A1: JP4.10, U2.24
A2: JP4.9, U2.25
A3: JP4.8, U2.26
A4: JP4.7, U2.27
A5: JP4.6, U2.28
A6: JP5.1, U2.19
A7: JP5.2, U2.22
A8: JP9.11, U5.23
A9: JP9.10, U5.24
A10: JP9.9, U5.25
A11: JP9.8, U5.26
A12: JP9.7, U5.27
A13: JP9.6, U5.28
A14: JP7.1, U5.19
A15: JP7.2, U5.22
A16: JP14.11, U8.23
A17: JP14.10, U8.24
A18: JP14.9, U8.25
A19: JP14.8, U8.26
A20: JP14.7, U8.27
A21: JP14.6, U8.28
A22: JP12.1, U8.19
A23: JP12.2, U8.22
A24: JP19.11, U11.23
A25: JP19.10, U11.24
A26: JP19.9, U11.25
A27: JP19.8, U11.26
A28: JP19.7, U11.27
A29: JP19.6, U11.28
A30: JP17.1, U11.19
A31: JP17.2, U11.22
A32: JP24.11, U14.23
A33: JP24.10, U14.24
A34: JP24.9, U14.25
A35: JP24.8, U14.26
A36: JP24.7, U14.27
A37: JP24.6, U14.28
A38: JP22.1, U14.19
A39: JP22.2, U14.22
A40: JP29.11, U17.23
A41: JP29.10, U17.24
A42: JP29.9, U17.25
A43: JP29.8, U17.26
A44: JP29.7, U17.27
A45: JP29.6, U17.28
A46: JP27.1, U17.19
A47: JP27.2, U17.22
A48: JP34.11, U20.23
A49: JP34.10, U20.24
A50: JP34.9, U20.25
A51: JP34.8, U20.26
A52: JP34.7, U20.27
A53: JP34.6, U20.28
A54: JP32.1, U20.19
A55: JP32.2, U20.22
A56: JP39.11, U23.23
A57: JP39.10, U23.24
A58: JP39.9, U23.25
A59: JP39.8, U23.26
A60: JP39.7, U23.27
A61: JP39.6, U23.28
A62: JP37.1, U23.19
A63: JP37.2, U23.22
A64: JP44.11, U26.23
A65: JP44.10, U26.24
A66: JP44.9, U26.25
A67: JP44.8, U26.26
A68: JP44.7, U26.27
A69: JP44.6, U26.28
A70: JP42.1, U26.19
A71: JP42.2, U26.22
A72: JP49.11, U29.23
A73: JP49.10, U29.24
A74: JP49.9, U29.25
A75: JP49.8, U29.26
A76: JP49.7, U29.27
A77: JP49.6, U29.28
A78: JP47.1, U29.19
A79: JP47.2, U29.22
A80: JP54.11, U32.23
A81: JP54.10, U32.24
A82: JP54.9, U32.25
A83: JP54.8, U32.26
A84: JP54.7, U32.27
A85: JP54.6, U32.28
A86: JP52.1, U32.19
A87: JP52.2, U32.22
A88: JP59.11, U35.23
A89: JP59.10, U35.24
A90: JP59.9, U35.25
A91: JP59.8, U35.26
A92: JP59.7, U35.27
A93: JP59.6, U35.28
A94: JP57.1, U35.19
A95: JP57.2, U35.22
A96: JP64.11, U38.23
A97: JP64.10, U38.24
A98: JP64.9, U38.25
A99: JP64.8, U38.26
A100: JP64.7, U38.27
A101: JP64.6, U38.28
A102: JP62.1, U38.19
A103: JP62.2, U38.22
A104: JP69.11, U41.23
A105: JP69.10, U41.24
A106: JP69.9, U41.25
A107: JP69.8, U41.26
A108: JP69.7, U41.27
A109: JP69.6, U41.28
A110: JP67.1, U41.19
A111: JP67.2, U41.22
A112: JP74.11, U44.23
A113: JP74.10, U44.24
A114: JP74.9, U44.25
A115: JP74.8, U44.26
A116: JP74.7, U44.27
A117: JP74.6, U44.28
A118: JP72.1, U44.19
A119: JP72.2, U44.22
A120: JP79.11, U47.23
A121: JP79.10, U47.24
A122: JP79.9, U47.25
A123: JP79.8, U47.26
A124: JP79.7, U47.27
A125: JP79.6, U47.28
A126: JP77.1, U47.19
A127: JP77.2, U47.22
A128: JP84.11, U50.23
A129: JP84.10, U50.24
A130: JP84.9, U50.25
A131: JP84.8, U50.26
A132: JP84.7, U50.27
A133: JP84.6, U50.28
A134: JP82.1, U50.19
A135: JP82.2, U50.22
A136: JP89.11, U53.23
A137: JP89.10, U53.24
A138: JP89.9, U53.25
A139: JP89.8, U53.26
A140: JP89.7, U53.27
A141: JP89.6, U53.28
A142: JP87.1, U53.19
A143: JP87.2, U53.22
A144: JP94.11, U56.23
A145: JP94.10, U56.24
A146: JP94.9, U56.25
A147: JP94.8, U56.26
A148: JP94.7, U56.27
A149: JP94.6, U56.28
A150: JP92.1, U56.19
A151: JP92.2, U56.22
A152: JP99.11, U59.23
A153: JP99.10, U59.24
A154: JP99.9, U59.25
A155: JP99.8, U59.26
A156: JP99.7, U59.27
A157: JP99.6, U59.28
A158: JP97.1, U59.19
A159: JP97.2, U59.22
A160: JP104.11, U62.23
A161: JP104.10, U62.24
A162: JP104.9, U62.25
A163: JP104.8, U62.26
A164: JP104.7, U62.27
A165: JP104.6, U62.28
A166: JP102.1, U62.19
A167: JP102.2, U62.22
A168: JP109.11, U65.23
A169: JP109.10, U65.24
A170: JP109.9, U65.25
A171: JP109.8, U65.26
A172: JP109.7, U65.27
A173: JP109.6, U65.28
A174: JP107.1, U65.19
A175: JP107.2, U65.22
A176: JP114.11, U68.23
A177: JP114.10, U68.24
A178: JP114.9, U68.25
A179: JP114.8, U68.26
A180: JP114.7, U68.27
A181: JP114.6, U68.28
A182: JP112.1, U68.19
A183: JP112.2, U68.22
A184: JP119.11, U71.23
A185: JP119.10, U71.24
A186: JP119.9, U71.25
A187: JP119.8, U71.26
A188: JP119.7, U71.27
A189: JP119.6, U71.28
A190: JP117.1, U71.19
A191: JP117.2, U71.22
A192: JP124.11, U74.23
A193: JP124.10, U74.24
A194: JP124.9, U74.25
A195: JP124.8, U74.26
A196: JP124.7, U74.27
A197: JP124.6, U74.28
A198: JP122.1, U74.19
A199: JP122.2, U74.22
A200: JP129.11, U77.23
A201: JP129.10, U77.24
A202: JP129.9, U77.25
A203: JP129.8, U77.26
A204: JP129.7, U77.27
A205: JP129.6, U77.28
A206: JP127.1, U77.19
A207: JP127.2, U77.22
A208: JP134.11, U80.23
A209: JP134.10, U80.24
A210: JP134.9, U80.25
A211: JP134.8, U80.26
A212: JP134.7, U80.27
A213: JP134.6, U80.28
A214: JP132.1, U80.19
A215: JP132.2, U80.22
A216: JP139.11, U83.23
A217: JP139.10, U83.24
A218: JP139.9, U83.25
A219: JP139.8, U83.26
A220: JP139.7, U83.27
A221: JP139.6, U83.28
A222: JP137.1, U83.19
A223: JP137.2, U83.22
A224: JP144.11, U86.23
A225: JP144.10, U86.24
A226: JP144.9, U86.25
A227: JP144.8, U86.26
A228: JP144.7, U86.27
A229: JP144.6, U86.28
A230: JP142.1, U86.19
A231: JP142.2, U86.22
A232: JP149.11, U89.23
A233: JP149.10, U89.24
A234: JP149.9, U89.25
A235: JP149.8, U89.26
A236: JP149.7, U89.27
A237: JP149.6, U89.28
A238: JP147.1, U89.19
A239: JP147.2, U89.22
A240: JP154.11, U92.23
A241: JP154.10, U92.24
A242: JP154.9, U92.25
A243: JP154.8, U92.26
A244: JP154.7, U92.27
A245: JP154.6, U92.28
A246: JP152.1, U92.19
A247: JP152.2, U92.22
A248: JP159.11, U95.23
A249: JP159.10, U95.24
A250: JP159.9, U95.25
A251: JP159.8, U95.26
A252: JP159.7, U95.27
A253: JP159.6, U95.28
A254: JP157.1, U95.19
A255: JP157.2, U95.22
A256: JP164.11, U98.23
A257: JP164.10, U98.24
A258: JP164.9, U98.25
A259: JP164.8, U98.26
A260: JP164.7, U98.27
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

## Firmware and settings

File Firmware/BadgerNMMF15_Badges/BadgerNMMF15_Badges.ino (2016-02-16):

/****************************************************************
BadgerNMMF15_Badges.ino
NoCo Mini Maker Faire 2015 Badger
Shawn Hymel @ SparkFun Electronics
Nick Poole @ SparkFun Electronics
Kade Drobeck @ SparkFun Electronics
August 19, 2015
https://github.com/sparkfun/BadgerStick

Receives commands from the #BadgerHack stations to display
custom text and graphics.

Hardware Connections:

IMPORTANT:  The Charlieplex LED board is designed for 2.0 - 3.3V!
            Higher voltages can damage the LEDs.

 Arduino Pin | Charlieplex Board
 ------------|------------------
      2      |         2
      3      |         3
      4      |         4
      5      |         5
      6      |         6
      7      |         7
      8      |         8
      9      |         9

Resources:
Include SoftwareSerial.h, Chaplex.h, SparkFun_LED_8x7.h, EEPROM.h
The Chaplex library can be found at: 
http://playground.arduino.cc/Code/Chaplex

Development environment specifics:
Written in Arduino 1.6.3
Tested with SparkFun BadgerStick (Interactive Badge)

This code is beerware; if you see me (or any other SparkFun 
employee) at the local, and you've found our code helpful, please
buy us a round!

Distributed as-is; no warranty is given.
****************************************************************/

#include <EEPROM.h>
#include <SoftwareSerial.h>
#include <SparkFun_LED_8x7.h>
#include <Chaplex.h>

// Parameters
#define DEBUG             1
#define LED_PIN           13
#define MAX_ACTIONS       30    // Number of actions per loop
#define MAX_TEXT_LENGTH   20    // Number of characters (>7)
#define BITMAP_DISP_TIME  2000  // Time (ms) to pause on bitmap
#define FRAME_DISP_TIME   100   // Time (ms) to pause on frame
#define CONWAY_NUM_GENS   20    // Number of generations
#define CONWAY_DISP_TIME  100   // Time (ms) to pause generation
#define RAIN_DISP_TIME    50    // Time (ms) between frames
#define RX_DELAY          500   // Time to wait for buffer to fill
#define INITIAL_TIMEOUT   10    // Waiting for first data (ms)
#define TRANSFER_TIMEOUT  1000  // Waiting for more data (ms)

// Communications constants
#define SOFT_BAUD_RATE    1200
#define MAX_PAYLOAD_SIZE  MAX_TEXT_LENGTH + 2
#define IN_BUF_MAX        MAX_PAYLOAD_SIZE + 2
#define SERIAL_BEGIN      0x55
#define SERIAL_SOF        0xD5
#define SERIAL_EOF        0xAA
#define HEADER_CLEAR      0x01
#define HEADER_TEXT       0x02
#define HEADER_BITMAP     0x03
#define HEADER_FRAME      0x04
#define HEADER_CONWAY     0x05
#define HEADER_ANIMATION  0x06
#define HEADER_ACK        0xAC
#define HEADER_BREAK      0xBE

// Animation constants
#define ANIM_RAIN         1
#define ANIM_EXPLOSIONS   2

// Other constants
#define BITMAP_SIZE       7     // Number of bytes in bitmap
#define BITS_PER_BYTE     8
#define PROD_TEST_SUCCESS 0xAB  // Value expected in EEPROM

// EEPROM addresses
#define ADDR_NUM_ACTIONS    0    // Total number of actions
#define ADDR_LIST_START     1    // Starting addr of actions list
#define ADDR_TABLE_START    ADDR_LIST_START + MAX_ACTIONS
#define ADDR_PROD_TEST      1023

// Initial animation, bitmap, and text
const byte flame00[] = {0x00, 0x00, 0x00, 0x00, 0x00, 0x00, 0x04};
const byte flame01[] = {0x00, 0x00, 0x00, 0x00, 0x00, 0x0C, 0x04};
const byte flame02[] = {0x00, 0x00, 0x00, 0x00, 0x3C, 0x0C, 0x04};
const byte flame03[] = {0x00, 0x00, 0x00, 0x7C, 0x3C, 0x0C, 0x04};
const byte flame04[] = {0x00, 0x00, 0x74, 0x7C, 0x3C, 0x0C, 0x04};
const byte flame05[] = {0x00, 0x50, 0x74, 0x7C, 0x3C, 0x0C, 0x04};
const byte flame06[] = {0x10, 0x50, 0x74, 0x7C, 0x3C, 0x0C, 0x04};
const byte conway_start[] = {0x00, 0x00, 0x00, 0x00, 0x60,
                                                0xA0,0x20};
const char initial_text[] = "#BadgerHack";

// Global variables for production test
int A0PinSet[] = {2, 4, 6, 8, 10, 16, 18};//7 pins
int A1PinSet[] = {3, 5, 7, 9, 17, 19};//6 pins
int ALLPINS[] = {2, 3, 4, 5, 6, 7, 8, 9, 10, 16 ,17, 18, 19, 14, 15};//15 pins
int STAT = 13;
int A0TEST = 0;
int A1TEST = 0;
int A0_1error = 0;
int A0_2error = 0;
int A1_1error = 0;
int A1_2error = 0;
int pin_read1error = 0;
int pin_read2error = 0;
int A6val;
int A7val;

// Global variables
SoftwareSerial softy(11, 10);  // RX, TX
byte out_msg[MAX_PAYLOAD_SIZE];
byte in_msg[MAX_PAYLOAD_SIZE];
uint8_t bytes_received;
static byte led_pins[] = {2, 3, 4, 5, 6, 7, 8, 9};
uint8_t action_cnt;
uint8_t prev_action;
uint16_t timeout;

/***************************************************************
 * Main
 **************************************************************/

// Run once
void setup() {
  
  uint8_t i;
  const byte *ptr;
  uint8_t animation;
  
  // Setup onboard LED for debugging
  pinMode(LED_PIN, OUTPUT);
  
  // Initialize serial comms
#if DEBUG
  Serial.begin(9600);
  Serial.println(F("NMMF '15 Badgers"));
  Serial.println();
  Serial.println(F("EEPROM ADDRESSES"));
  Serial.print(F("num_actions: "));
  Serial.println(ADDR_NUM_ACTIONS, DEC);
  Serial.print(F("Actions list: "));
  Serial.print(ADDR_LIST_START, DEC);
  Serial.print(F(" - "));
  Serial.println(ADDR_LIST_START + MAX_ACTIONS - 1, DEC);
  Serial.print(F("Actions table: "));
  Serial.print(ADDR_TABLE_START, DEC);
  Serial.print(F(" - "));
  Serial.println(ADDR_TABLE_START + (MAX_ACTIONS * 
                          MAX_TEXT_LENGTH) - 1, DEC);
  Serial.print(F("Production Test: "));
  Serial.println(ADDR_PROD_TEST, DEC);
  Serial.println();
#endif

  // If we have not passed production test, fill default actions
  if ( EEPROM.read(ADDR_PROD_TEST) != PROD_TEST_SUCCESS ) {
    clearActions();
    ptr = conway_start;
    addAction(HEADER_CONWAY, ptr, 0);
    ptr = flame00;
    addAction(HEADER_FRAME, ptr, 0);
    ptr = flame01;
    addAction(HEADER_FRAME, ptr, 0);
    ptr = flame02;
    addAction(HEADER_FRAME, ptr, 0);
    ptr = flame03;
    addAction(HEADER_FRAME, ptr, 0);
    ptr = flame04;
    addAction(HEADER_FRAME, ptr, 0);
    ptr = flame05;
    addAction(HEADER_FRAME, ptr, 0);
    for ( i = 0; i < 15; i++ ) {
      ptr = flame06;
      addAction(HEADER_FRAME, ptr, 0);
    }
    animation = ANIM_RAIN;
    addAction(HEADER_ANIMATION, &animation, 0);
    ptr = (const byte*)initial_text;
    addAction(HEADER_TEXT, ptr, strlen(initial_text));
  }

  // Production test code
  while ( EEPROM.read(ADDR_PROD_TEST) != PROD_TEST_SUCCESS ) {
    test_code();
  }
  
  // Initialize the software serial port
  softy.begin(SOFT_BAUD_RATE);
  
  // Seed the RNGesus
  randomSeed(analogRead(0));
  
  // Blink a few times to show that we are alive
  for ( i = 0; i < 3; i++ ) {
    digitalWrite(LED_PIN, HIGH);
    delay(100);
    digitalWrite(LED_PIN, LOW);
    delay(100);
  }
  
  // Initialize LED array
  Plex.init(led_pins);
  
  // Initialize action counter
  action_cnt = 0;
  
  // Initialize checking
  prev_action = 0;
}

// Superloop
void loop() {
  
  Serial.print("Prev: ");
  Serial.print(prev_action, DEC);
  Serial.print(" Current: ");
  Serial.println(EEPROM.read(ADDR_LIST_START + action_cnt), DEC);
  
  // Skip transfers if middle of animation
  if ( ((prev_action != HEADER_FRAME) ||
      (EEPROM.read(ADDR_LIST_START + action_cnt) != 
      HEADER_FRAME)) || action_cnt == 0 ) {
        
    // Clear LEDs
    Plex.clear();
    Plex.display();
  
    // Try sending the BREAK message
    out_msg[0] = HEADER_BREAK;
#if DEBUG
    Serial.print(F("Sending: 0x"));
    Serial.println(out_msg[0], HEX);
#endif
    transmitMessage(out_msg, 1);
    
    // Magic delay to let input buffer fill
    delay(RX_DELAY);
    
    // Get message, add action, send ACK until timeout
    timeout = INITIAL_TIMEOUT;
    while ( true ) {
      memset(in_msg, 0, MAX_PAYLOAD_SIZE);
      bytes_received = receiveMessage(in_msg, timeout);
    
      // See if anything was received. If not, exit loop.
      if ( bytes_received > 0 ) {
      
        // Print the message received
#if DEBUG
        Serial.print(F("Received: "));
        for ( uint8_t i = 0; i < bytes_received; i++ ) {
          Serial.print(F("0x"));
          Serial.print(in_msg[i], HEX);
          Serial.print(F(" "));
        }
        Serial.println();
#endif
        // We got a response! Make timeout longer
        timeout = TRANSFER_TIMEOUT;

      } else {
        break;
      }
      
      // Send ACK
      out_msg[0] = HEADER_ACK;
#if DEBUG
    Serial.print(F("Sending: 0x"));
    Serial.println(out_msg[0], HEX);
#endif
      transmitMessage(out_msg, 1);
      
      // Clear or add action as per the message
      interpretMessage();
    }
  }
  
  // Perform desired action and update counter
  if ( EEPROM.read(ADDR_NUM_ACTIONS) > 0 ) {
    performAction(action_cnt);
    prev_action = EEPROM.read(ADDR_LIST_START + action_cnt);
    action_cnt = (action_cnt + 1) % EEPROM.read(ADDR_NUM_ACTIONS);
  }
}

/***************************************************************
 * High Level Main Functions
 **************************************************************/
 
// Read the receive buffer and add the listed action
void interpretMessage() {
  
  const byte *ptr;
  char text[MAX_TEXT_LENGTH];
  uint8_t animation = 0;

  // Read the header
  switch ( in_msg[0] ) {
  
    // Clear the actions
    case HEADER_CLEAR:
#if DEBUG
      Serial.println(F("Clearing actions"));
#endif
      clearActions();
      break;
          
    // Add text
    case HEADER_TEXT:
#if DEBUG
      Serial.println(F("Adding text"));
#endif
      ptr = (const byte*)(in_msg + 2);
      addAction(HEADER_TEXT, ptr, in_msg[1]);
      break;
      
    // Add bitmap
    case HEADER_BITMAP:
#if DEBUG
      Serial.println(F("Adding bitmap"));
#endif
      ptr = (const byte *)(in_msg + 1);
      addAction(HEADER_BITMAP, ptr, 0);
      break;
      
    // Add frame
    case HEADER_FRAME:
#if DEBUG
      Serial.println(F("Adding frame"));
#endif
      ptr = (const byte *)(in_msg + 1);
      addAction(HEADER_FRAME, ptr, 0);
      break;
      
    // Add Conway's Game of Life
    case HEADER_CONWAY:
#if DEBUG
      Serial.println(F("Adding Conway"));
#endif
      ptr = (const byte *)(in_msg + 1);
      addAction(HEADER_CONWAY, ptr, 0);
      break;
      
      // Add math animation
    case HEADER_ANIMATION:
#if DEBUG
      Serial.print(F("Adding animation #"));
      Serial.println(in_msg[1]);
#endif
      animation = in_msg[1];
      addAction(HEADER_ANIMATION, &animation, 0);
      break;

    // Unknown header
    default:
      break;
  }
}

/***************************************************************
 * Communication Functions
 **************************************************************/

// Transmit message with BEGIN, SOF, Checksum, and EOF bytes
void transmitMessage(byte msg[], uint8_t len) {
  
  int i;
  byte cs;
  byte *out_buf;
  uint8_t buf_size;
  
  // If message is greater than max size, only xmit max bytes
  if ( len > MAX_PAYLOAD_SIZE ) {
    len = MAX_PAYLOAD_SIZE;
  }
  
  // Full buffer is message + BEGIN, SOF, CS, EOF bytes
  buf_size = len + 4;
  
  // Calculate checksum
  cs = createChecksum(msg, len);
  
  // Create the output buffer with BEGIN, SOF, CS, and EOF
  out_buf = (byte*)malloc(buf_size * sizeof(byte));
  out_buf[0] = SERIAL_BEGIN;
  out_buf[1] = SERIAL_SOF;
  memcpy(out_buf + 2, msg, len);
  out_buf[buf_size - 2] = cs;
  out_buf[buf_size - 1] = SERIAL_EOF;
  
  // Transmit buffer
  for ( i = 0; i < buf_size; i++ ) {
    softy.write(out_buf[i]);
  }
  
  // Free some memory
  free(out_buf);
}

// Receive a message (number of bytes received is returned)
// Timeout is in ms. 0 timeout means wait forever (blocking).
uint8_t receiveMessage(byte msg[], unsigned long timeout) {
  
  boolean valid;
  uint8_t buf_idx;
  unsigned long start_time;
  byte in_buf[IN_BUF_MAX];
  byte r;
  
  // Our receiver. Wait until we get a valid message or time out
  start_time = millis();
  valid = false;
  while ( !valid ) {
    
    // Wait until we see a Start of Frame (SOF) or time out
    memset(in_buf, 0, IN_BUF_MAX);
    while ( !softy.available() ) {
      if ( (millis() - start_time > timeout) && (timeout > 0) ) {
        return 0;
      }
    }
    r = softy.read();
    if ( r != SERIAL_SOF ) {
      continue;
    }
    
    // Read buffer
    delay(2);  // Magical delay to let the buffer fill up
    buf_idx = 0;
    while ( softy.available() > 0 ) {
      if ( buf_idx >= IN_BUF_MAX ) {
        buf_idx = IN_BUF_MAX - 1;
      }
      in_buf[buf_idx] = softy.read();
      Serial.print("0x");
      Serial.print(in_buf[buf_idx], HEX);
      Serial.print(" ");
      buf_idx++;
      delay(2);  // Magical delay to let the buffer fill up
    }
    Serial.println();
    
    // End of Frame (EOF) check
    if ( in_buf[buf_idx - 1] != SERIAL_EOF ) {
      continue;
    }
    
    // Verify the checksum
    if ( verifyChecksum(in_buf, buf_idx - 1) ) {
      valid = 1;
    }
  }
  
  // Copy our message (don't copy checksum or EOF bytes)
  memcpy(msg, in_buf, buf_idx - 2);
  
  return buf_idx - 2;
}

// Calculate checksum (ignore Begin and SOF bytes)
byte createChecksum(byte buf[], uint8_t len) {
  
  uint8_t i;
  byte sum;
  
  // XOR all bytes in the message
  sum = 0;
  for ( i = 0; i < len; i++ ) {
    sum ^= buf[i];
  }
  
  return sum;
}

// Check the checksum
boolean verifyChecksum(byte buf[], uint8_t len) {
  
  uint8_t i;
  byte sum;
  
  // XOR all bytes in the message (including checksum byte)
  sum = 0;
  for ( i = 0; i < len; i++ ) {
    sum ^= buf[i];
  }
  
  // Sum should be 0 if the checksum is correct
  return (sum ? false : true);
}

/***************************************************************
 * High Level Draw Functions
 **************************************************************/

// Clear all actions from the table
void clearActions() {
  
  uint16_t i;
  
  // Clear actions list
  for(i = ADDR_LIST_START; i < ADDR_LIST_START + MAX_ACTIONS; i++){
    EEPROM.update(i, 0);
  }
  
  // Clear actions length and counter
  EEPROM.update(ADDR_NUM_ACTIONS, 0);
  action_cnt = 0;
}

// Add an action to the table
bool addAction(uint8_t action, const byte *buf, uint8_t len) {
  
  uint8_t i;
  
  // Get the current number of actions
  uint8_t num_actions = EEPROM.read(ADDR_NUM_ACTIONS);
  
  // If we are at max actions, don't add anything
  if ( num_actions + 1 > MAX_ACTIONS ) {
    return false;
  }
  
  // Predefine the offset into the actions table
  uint16_t offset = num_actions * MAX_TEXT_LENGTH;
  
  // Say which action we are adding
#if DEBUG
  Serial.print(F("Adding action: "));
  Serial.println(action);
#endif
                    
  // What action we add is based on the action header
  switch ( action ) {
    
    // Add text to the buffer (clear it first)
    case HEADER_TEXT:
      for ( i = 0; i < MAX_TEXT_LENGTH; i++ ) {
        EEPROM.update(ADDR_TABLE_START + offset + i, 0);
      }
      EEPROM.update(ADDR_LIST_START + num_actions, HEADER_TEXT);
      if ( len >= MAX_TEXT_LENGTH ) {
        len = MAX_TEXT_LENGTH;
      }
      for ( i = 0; i < len; i++ ) {
        EEPROM.update(ADDR_TABLE_START + offset + i, buf[i]);
      }
      break;
      
    // Add bitmap to the buffer
    case HEADER_BITMAP:
      EEPROM.update(ADDR_LIST_START + num_actions, HEADER_BITMAP);
      for ( i = 0; i < BITMAP_SIZE; i++ ) {
        EEPROM.update(ADDR_TABLE_START + offset + i, buf[i]);
      }
      break;
      
    // Add frame to the buffer
    case HEADER_FRAME:
      EEPROM.update(ADDR_LIST_START + num_actions, HEADER_FRAME);
      for ( i = 0; i < BITMAP_SIZE; i++ ) {
        EEPROM.update(ADDR_TABLE_START + offset + i, buf[i]);
      }
      break;
      
    // Add Conway's game to buffer
    case HEADER_CONWAY:
      EEPROM.update(ADDR_LIST_START + num_actions, HEADER_CONWAY);
      for ( i = 0; i < BITMAP_SIZE; i++ ) {
        EEPROM.update(ADDR_TABLE_START + offset + i, buf[i]);
      }
      break;
      
    // Add math animation to buffer
    case HEADER_ANIMATION:
      EEPROM.update(ADDR_LIST_START + num_actions, 
                                              HEADER_ANIMATION);
      EEPROM.update(ADDR_TABLE_START + offset + i, *buf);
      break;
      
    // Unknown case. Exit.
    default:
      return false;
  }
  
  // Increment number of actions
  EEPROM.update(ADDR_NUM_ACTIONS, num_actions + 1);
  
  return true;
}

// Perform the desired action based on the number provided
void performAction(uint8_t index) {
  
  uint8_t i;
  
  // Make sure index is not out of range
  if ( index >= EEPROM.read(ADDR_NUM_ACTIONS) ) {
    return;
  }
  
  // Predefine the offset into the actions table
  uint16_t offset = index * MAX_TEXT_LENGTH;
  
  // Get the desired action
  uint8_t action = EEPROM.read(ADDR_LIST_START + index);
  
   // Say which action we are about to do
#if DEBUG
  Serial.print(F("Performing action: "));
  Serial.println(action);
#endif

  // Do the thing we said we would do
  switch ( action ) {
    
    // Scroll text once
    case HEADER_TEXT:
      Plex.clear();
      Plex.display();
      char text_buf[MAX_TEXT_LENGTH + 1];
      memset(text_buf, 0, MAX_TEXT_LENGTH + 1);
      for ( i = 0; i < MAX_TEXT_LENGTH; i++ ) {
        text_buf[i] = EEPROM.read(ADDR_TABLE_START + offset + i);
      }
      Plex.scrollText(text_buf, 1, true);
      break;
      
    // Show bitmap for a set amount of time
    case HEADER_BITMAP:
      showBitmap(offset, BITMAP_DISP_TIME);
      break;
      
    // Show bitmap (frame) for a short amount of time
    case HEADER_FRAME:
      showBitmap(offset, FRAME_DISP_TIME);
      break;
      
    // Play Conway's game of live
    case HEADER_CONWAY:
      playConway(offset, CONWAY_NUM_GENS);
      break;
      
    // Show a math-based animation
    case HEADER_ANIMATION:
      switch ( EEPROM.read(ADDR_TABLE_START + offset) ) {
        case ANIM_RAIN:
          makeItRain();
          delay(500);
          break;
          
         case ANIM_EXPLOSIONS:
           showExplosions();
           break;
           
          default:
            return;
      }
      break;
    
    // Unknown index. End.
    default:
      return;
 }
}

/***************************************************************
 * Low Level Animation/Display Functions
 **************************************************************/

// Display a bitmap on the LEDs for a given amount of time
void showBitmap(uint16_t offset, unsigned long time) {
  
  byte bitmap_buf[NUM_LEDS];
  
  // Translate bytes to bit array
  for ( uint8_t y = 0; y < BITMAP_SIZE; y++ ) {
    for ( uint8_t i = 0; i < BITS_PER_BYTE; i++ ) {
      bitmap_buf[(y * BITS_PER_BYTE) + i] = 
          (EEPROM.read(ADDR_TABLE_START + offset + y) >> i) & 0x01;
    }
  }
  
  // Draw on LEDs
  Plex.drawBitmap(bitmap_buf);
  Plex.display();
  
  // Wait for the specified time (ms)
  delay(time);
}

// Play Conway's Game of Life
void playConway(uint16_t offset, uint16_t num_gens) {
  
  byte gol_1[NUM_LEDS];
  byte gol_2[NUM_LEDS];
  byte *gol_prev;
  byte *gol_new;
  bool gol_swap = true;
  uint8_t cell_state;
  uint8_t neighbors;
  uint16_t g;
  int8_t x;
  int8_t y;
  int8_t rx;
  int8_t ry;
  
  // Translate bytes to bit array
  for ( y = 0; y < BITMAP_SIZE; y++ ) {
    for ( x = 0; x < BITS_PER_BYTE; x++ ) {
      gol_1[(y * BITS_PER_BYTE) + x] = 
          (EEPROM.read(ADDR_TABLE_START + offset + y) >> x) & 0x01;
    }
  }
  
    // Show initial state
  Plex.drawBitmap(gol_1);
  Plex.display();
  delay(CONWAY_DISP_TIME);
  
  // Play Conway's game for a number of generations
  for ( g = 0; g < num_gens; g++ ) {
    
    // Swap array pointers
    if ( gol_swap ) {
      gol_prev = gol_1;
      gol_new = gol_2;
      gol_swap = false;
    } else {
      gol_prev = gol_2;
      gol_new = gol_1;
      gol_swap = true;
    }
    
    // Go through each cell
    for ( y = 0; y < COL_SIZE; y++ ) {
      for ( x = 0; x < ROW_SIZE; x++ ) {
        
        // Determine if cell is alive or dead
        cell_state = gol_prev[(y * ROW_SIZE) + x];
        
        // Count number of alive neighbors (8 directions)
        neighbors = 0;
        for ( ry = -1; ry <= 1; ry++ ) {
          
          // Don't want to go past array bounds
          if ( ((y + ry) < 0) || ((y + ry) >= COL_SIZE) ) {
            continue;
          }
          
          for ( rx = -1; rx <= 1; rx++ ) {
            
            // Don't want to go past array bounds
            if ( ((x + rx) < 0) || ((x + rx) >= ROW_SIZE) ) {
              continue;
            }
            
            // Don't want to count self
            if ( (rx == 0) && (ry == 0) ) {
              continue;
            }
            
            // Only count alive neighbors
            if (gol_prev[((y + ry) * ROW_SIZE) + (x + rx)] == 1) {
              neighbors++;
            }
          }
        }
        
        // See if the cell lives or dies in next generation
        if ( ((cell_state == 1) && (neighbors == 2)) ||
                                         (neighbors == 3) ) {
          gol_new[(y * ROW_SIZE) + x] = 1;
        } else {
          gol_new[(y * ROW_SIZE) + x] = 0;
        }
      }
    }
    
    // Print next generation to Serial
#if 0
    for ( uint8_t j = 0; j < COL_SIZE; j++ ) {
      for ( uint8_t i = 0; i < ROW_SIZE; i++ ) {
        Serial.print(gol_new[(j * ROW_SIZE) + i]);
      }
      Serial.println();
    }
    Serial.println();
#endif
    
    // Show generation
    Plex.drawBitmap(gol_new);
    Plex.display();
    delay(CONWAY_DISP_TIME);
  }
}
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

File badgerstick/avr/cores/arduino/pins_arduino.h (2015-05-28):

/*
  pins_arduino.h - Pin definition functions for Arduino
  Part of Arduino - http://www.arduino.cc/

  Copyright (c) 2007 David A. Mellis
  Modified by Shawn Hymel @ SparkFun Electronics to support the BadgerStick

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
  $Id: wiring.h 249 2007-02-03 16:52:51Z mellis $
*/

#ifndef Pins_Arduino_h
#define Pins_Arduino_h

#include <avr/pgmspace.h>

#define NUM_DIGITAL_PINS            20
#define NUM_ANALOG_INPUTS           8
#define analogInputToDigitalPin(p)  ((p < 6) ? (p) + 14 : -1)

#if defined(__AVR_ATmega8__)
#define digitalPinHasPWM(p)         ((p) == 9 || (p) == 10 || (p) == 11)
#else
#define digitalPinHasPWM(p)         ((p) == 3 || (p) == 5 || (p) == 6 || (p) == 9 || (p) == 10 || (p) == 11)
#endif

static const uint8_t SS   = 10;
static const uint8_t MOSI = 11;
static const uint8_t MISO = 12;
static const uint8_t SCK  = 13;

static const uint8_t SDA = 18;
static const uint8_t SCL = 19;
#define LED_BUILTIN 13

static const uint8_t A0 = 14;
static const uint8_t A1 = 15;
static const uint8_t A2 = 16;
static const uint8_t A3 = 17;
static const uint8_t A4 = 18;
static const uint8_t A5 = 19;
static const uint8_t A6 = 20;
static const uint8_t A7 = 21;

#define digitalPinToPCICR(p)    (((p) >= 0 && (p) <= 21) ? (&PCICR) : ((uint8_t *)0))
#define digitalPinToPCICRbit(p) (((p) <= 7) ? 2 : (((p) <= 13) ? 0 : 1))
#define digitalPinToPCMSK(p)    (((p) <= 7) ? (&PCMSK2) : (((p) <= 13) ? (&PCMSK0) : (((p) <= 21) ? (&PCMSK1) : ((uint8_t *)0))))
#define digitalPinToPCMSKbit(p) (((p) <= 7) ? (p) : (((p) <= 13) ? ((p) - 8) : ((p) - 14)))

#define digitalPinToInterrupt(p)  ((p) == 2 ? 0 : ((p) == 3 ? 1 : NOT_AN_INTERRUPT))

#ifdef ARDUINO_MAIN

// On the Arduino board, digital pins are also used
// for the analog output (software PWM).  Analog input
// pins are a separate set.

// ATMEL ATMEGA8 & 168 / ARDUINO
//
//                  +-\/-+
//            PC6  1|    |28  PC5 (AI 5)
//      (D 0) PD0  2|    |27  PC4 (AI 4)
//      (D 1) PD1  3|    |26  PC3 (AI 3)
//      (D 2) PD2  4|    |25  PC2 (AI 2)
// PWM+ (D 3) PD3  5|    |24  PC1 (AI 1)
//      (D 4) PD4  6|    |23  PC0 (AI 0)
//            VCC  7|    |22  GND
//            GND  8|    |21  AREF
//            PB6  9|    |20  AVCC
//            PB7 10|    |19  PB5 (D 13)
// PWM+ (D 5) PD5 11|    |18  PB4 (D 12)
// PWM+ (D 6) PD6 12|    |17  PB3 (D 11) PWM
//      (D 7) PD7 13|    |16  PB2 (D 10) PWM
//      (D 8) PB0 14|    |15  PB1 (D 9) PWM
//                  +----+
//
// (PWM+ indicates the additional PWM pins on the ATmega168.)

// ATMEL ATMEGA1280 / ARDUINO
//
// 0-7 PE0-PE7   works
// 8-13 PB0-PB5  works
// 14-21 PA0-PA7 works 
// 22-29 PH0-PH7 works
// 30-35 PG5-PG0 works
// 36-43 PC7-PC0 works
// 44-51 PJ7-PJ0 works
// 52-59 PL7-PL0 works
// 60-67 PD7-PD0 works
// A0-A7 PF0-PF7
// A8-A15 PK0-PK7


// these arrays map port names (e.g. port B) to the
// appropriate addresses for various functions (e.g. reading
// and writing)
const uint16_t PROGMEM port_to_mode_PGM[] = {
	NOT_A_PORT,
	NOT_A_PORT,
	(uint16_t) &DDRB,
	(uint16_t) &DDRC,
	(uint16_t) &DDRD,
};

const uint16_t PROGMEM port_to_output_PGM[] = {
	NOT_A_PORT,
	NOT_A_PORT,
	(uint16_t) &PORTB,
	(uint16_t) &PORTC,
	(uint16_t) &PORTD,
};

const uint16_t PROGMEM port_to_input_PGM[] = {
	NOT_A_PORT,
	NOT_A_PORT,
	(uint16_t) &PINB,
	(uint16_t) &PINC,
	(uint16_t) &PIND,
};

const uint8_t PROGMEM digital_pin_to_port_PGM[] = {
	PD, /* 0 */
	PD,
	PD,
	PD,
	PD,
	PD,
	PD,
	PD,
	PB, /* 8 */
	PB,
	PB,
	PB,
	PB,
	PB,
	PC, /* 14 */
	PC,
	PC,
	PC,
	PC,
	PC,
};

const uint8_t PROGMEM digital_pin_to_bit_mask_PGM[] = {
	_BV(0), /* 0, port D */
	_BV(1),
	_BV(2),
	_BV(3),
	_BV(4),
	_BV(5),
	_BV(6),
	_BV(7),
	_BV(0), /* 8, port B */
	_BV(1),
	_BV(2),
	_BV(3),
	_BV(4),
	_BV(5),
	_BV(0), /* 14, port C */
	_BV(1),
	_BV(2),
	_BV(3),
	_BV(4),
	_BV(5),
};

const uint8_t PROGMEM digital_pin_to_timer_PGM[] = {
	NOT_ON_TIMER, /* 0 - port D */
	NOT_ON_TIMER,
	NOT_ON_TIMER,
	// on the ATmega168, digital pin 3 has hardware pwm
#if defined(__AVR_ATmega8__)
	NOT_ON_TIMER,
#else
	TIMER2B,
#endif
	NOT_ON_TIMER,
	// on the ATmega168, digital pins 5 and 6 have hardware pwm
#if defined(__AVR_ATmega8__)
	NOT_ON_TIMER,
	NOT_ON_TIMER,
#else
	TIMER0B,
	TIMER0A,
#endif
	NOT_ON_TIMER,
	NOT_ON_TIMER, /* 8 - port B */
	TIMER1A,
	TIMER1B,
#if defined(__AVR_ATmega8__)
	TIMER2,
#else
	TIMER2A,
#endif
	NOT_ON_TIMER,
	NOT_ON_TIMER,
	NOT_ON_TIMER,
	NOT_ON_TIMER, /* 14 - port C */
	NOT_ON_TIMER,
	NOT_ON_TIMER,
	NOT_ON_TIMER,
	NOT_ON_TIMER,
};

#endif
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

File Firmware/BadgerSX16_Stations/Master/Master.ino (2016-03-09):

#include <FrequencyTimer2.h>

// Parameters
#define DEBUG             1
#define CLEAR_FIRST       1
#define RX_TIMEOUT        1000  // ms
#define MAX_TEXT_LENGTH   20    // Number of characters (>7)

// Other constants
#define BITMAP_SIZE       7     // Number of bytes in bitmap
#define BITS_PER_BYTE     8

// Communications constants
#define UART2_BAUD_RATE    1200
#define MAX_PAYLOAD_SIZE  MAX_TEXT_LENGTH + 2
#define IN_BUF_MAX        MAX_PAYLOAD_SIZE + 2
#define SERIAL_BEGIN      0x55
#define SERIAL_SOF        0xD5
#define SERIAL_EOF        0xAA
#define HEADER_CLEAR      0x01
#define HEADER_TEXT       0x02
#define HEADER_BITMAP     0x03
#define HEADER_FRAME      0x04
#define HEADER_CONWAY     0x05
#define HEADER_ANIMATION  0x06
#define HEADER_ACK        0xAC
#define HEADER_BREAK      0xBE

// Animation constants
#define ANIM_RAIN         1
#define ANIM_EXPLOSIONS   2

// Global variables
byte out_msg[MAX_PAYLOAD_SIZE];
byte in_msg[MAX_PAYLOAD_SIZE];
uint8_t bytes_received;
uint8_t led;
bool trig;
bool prev_trig;
bool transferring;
bool add_text;
bool add_image;
bool add_conway;
bool add_rain;
bool add_expl;
bool prev_text;
bool prev_image;
bool prev_conway;
bool prev_anim;
char send_anim;

int swtgnd[8] = {28, 29, 30, 31, 32, 33, 34, 35}; 
int swtdec[7] = {46, 45, 44, A4, A1, A5, A2};
int ledgnd[8] = {10, 11, 9, 12, 8, 13, 37, 36}; 
int ledvcc[7] = {53, 52, 51, 50, 49, 48, 47}; 

/*UNIT B 
int swtgnd[8] = {35, 34, 33, 32, 31, 30, 29, 28};
int swtdec[7] = {46, 45, 44, A4, A1, A5, A2};
int ledgnd[8] = {36, 37, 13, 8, 12, 9, 11, 10};
int ledvcc[7] = {53, 52, 51, 50, 49, 48, 47};
*/

bool frame[7][8] =
{
  {0, 0, 0, 0, 0, 0, 0, 0},
  {0, 0, 0, 0, 0, 0, 0, 0},
  {0, 0, 0, 0, 0, 0, 0, 0},
  {0, 0, 0, 0, 0, 0, 0, 0},
  {0, 0, 0, 0, 0, 0, 0, 0},
  {0, 0, 0, 0, 0, 0, 0, 0},
  {0, 0, 0, 0, 0, 0, 0, 0}
};

bool blankFrame[7][8] =
{
  {0, 0, 0, 0, 0, 0, 0, 0},
  {0, 0, 0, 0, 0, 0, 0, 0},
  {0, 0, 0, 0, 0, 0, 0, 0},
  {0, 0, 0, 0, 0, 0, 0, 0},
  {0, 0, 0, 0, 0, 0, 0, 0},
  {0, 0, 0, 0, 0, 0, 0, 0},
  {0, 0, 0, 0, 0, 0, 0, 0}
};

bool smile[7][8] =
{
  {0, 0, 0, 0, 0, 0, 0, 0},
  {0, 0, 0, 0, 0, 0, 0, 0},
  {0, 0, 1, 1, 1, 1, 0, 0},
  {0, 0, 1, 0, 0, 1, 0, 0},
  {0, 0, 1, 1, 1, 1, 0, 0},
  {0, 0, 0, 0, 0, 0, 0, 0},
  {0, 0, 0, 0, 0, 0, 0, 0}
};

bool picSwt = 0;
bool lastPicSwt = 0;
bool conSwt = 0;
bool txtSwt = 0;
bool xplSwt = 0;
bool ranSwt = 0;

char message[17] = "                ";
//char prevMessage[17] = "                ";

byte send_img[] = {0x00,0x00,0x00,0x00,0x00,0x00,0x00};

void setup() {

  for (int i = 0; i < 8; i++) {
    pinMode(ledgnd[i], OUTPUT);
    digitalWrite(ledgnd[i], HIGH);
  }

  for (int i = 0; i < 7; i++) {
    pinMode(ledvcc[i], OUTPUT);
    digitalWrite(ledvcc[i], LOW);
  }

  for (int i = 0; i < 8; i++) {
    pinMode(swtgnd[i], OUTPUT);
    digitalWrite(swtgnd[i], LOW);
  }

  for (int i = 0; i < 7; i++) {
    pinMode(swtdec[i], INPUT);
    digitalWrite(swtdec[i], HIGH);
  }

  FrequencyTimer2::disable();
  FrequencyTimer2::setPeriod(50000);
  FrequencyTimer2::setOnOverflow(scanOut);

  pinMode(A13, OUTPUT);
  digitalWrite(A13, LOW);

  pinMode(A14, INPUT);
  digitalWrite(A14, HIGH);

  Serial.begin(9600);
  Serial1.begin(57600);
  Serial2.begin(UART2_BAUD_RATE);

  #if DEBUG 
  Serial.println("I AM STATION");
  #endif 

  // Initialize globals
  trig = false;
  prev_trig = false;
  led = 0;
  transferring = false;
  add_text = false;
  add_image = false;
  add_conway = false;
  add_rain = false;
  add_expl = false;
  prev_text = false;
  prev_image = false;
  prev_conway = false;
  prev_anim = false;

  pinMode(20, OUTPUT);
  digitalWrite(20, LOW);

  pinMode(21, OUTPUT);
  digitalWrite(21, LOW);

}

void loop() {

  picSwt = digitalRead(A8);
  if(picSwt!=lastPicSwt){

    if(picSwt==0){clearFrame();}
    if(picSwt==1){newFrame();}

    lastPicSwt = picSwt;
  }
  
  if(picSwt==1){scanIn();}

  if(digitalRead(A14)==LOW){
  checkSwitches();
  checkText();
  formatImage();
  FrequencyTimer2::setOnOverflow(0);
  digitalWrite(21, HIGH);

while ( Serial2.available() > 0 ) {
      Serial2.read();
    }
  
  transferring = true;
    while ( transferring ) {
      doTransfer();
      delay(500);
    }
  
  
  FrequencyTimer2::setOnOverflow(scanOut);
  digitalWrite(21, LOW);
  }
  

}

void scanOut() {

  for (int x = 0; x < 8; x++) {

    for (int y = 0; y < 7; y++) {

      digitalWrite(ledvcc[y], frame[y][x]);

    }

    digitalWrite(ledgnd[x], 0);

    delay(1);

    digitalWrite(ledgnd[x], 1);

  }

}

void scanIn() {

  for (int x = 8; x >= 0; x--) {

      pinMode(swtgnd[x], OUTPUT); // Ground
      digitalWrite(swtgnd[x], LOW);

  for (int y = 0; y < 7; y++) {

      if (digitalRead(swtdec[y]) == 0) {

        frame[y][x] = !frame[y][x];
        delay(200);

      }

    }

    pinMode(swtgnd[x], INPUT); // Hi-Z
    digitalWrite(swtgnd[x], LOW);

  }
  
}

void checkSwitches(){

picSwt = digitalRead(A8);
conSwt = digitalRead(A9);
txtSwt = digitalRead(A10);
xplSwt = digitalRead(A11);
ranSwt = digitalRead(A12);

if(xplSwt==1){add_expl=true;}
else{add_expl=false;}
if(ranSwt==1){add_rain=true;}
else{add_rain=false;}
if(picSwt==1){add_image=true;}
else{add_image=false;}
if(txtSwt==1){add_text=true;}
else{add_text=false;}
if(conSwt==1){add_conway=true;}
else{add_conway=false;}

delay(500);

}

void checkText(){

    FrequencyTimer2::setOnOverflow(0);

int i = 0;

while(Serial1.available()){Serial1.read();}


for(int f = 0; f<10; f++){
i=0;
Serial1.write(200);
delay(10);
while(Serial1.available() && i<17){
message[i] = Serial1.read();
i++;}
delay(10);}

while(Serial1.available()){Serial1.read();}

Serial.println("Text Message:");
Serial.println("-------------");
Serial.println(message);
Serial.println();

//printFrame();

for ( i = 16; i >= 0; i-- ) {
  if ( message[i] == 0x20 || message[i] == 0x00 ) {
    message[i] = 0;
  } else {
    break;
  }
}
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

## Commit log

2014-06-20 Adding initial board design files
    [Interactive_SparkFun_Badge.brd, Interactive_SparkFun_Badge.sch]
2014-06-23 moving oscillator
    [Interactive_SparkFun_Badge.brd]
2014-06-23 Updating line widths
    [Interactive_SparkFun_Badge.brd, Interactive_SparkFun_Badge.sch]
2014-07-01 New board design
    [Interactive_SparkFun_Badge.brd, Interactive_SparkFun_Badge.sch]
2014-07-02 Updating with engineering review changes
    [Interactive_SparkFun_Badge.brd, Interactive_SparkFun_Badge.sch]
2014-08-05 Updating to round corners, zener diodes, larger letter boards
    [Interactive_SparkFun_Badge.brd, Interactive_SparkFun_Badge.sch]
2014-08-06 Updating to new power circuit, and adding front silk
    [Interactive_SparkFun_Badge.brd, Interactive_SparkFun_Badge.sch]
2014-08-06 Adding NY MF silk
    [Interactive_SparkFun_Badge.brd, Interactive_SparkFun_Badge.sch]
2014-08-21 Fixing line widths in schematic
    [Interactive_SparkFun_Badge.sch]
2014-12-10 Removed old badge hardware files.
    [Interactive_SparkFun_Badge.brd, Interactive_SparkFun_Badge.sch, SparkFun_Interactive_Badge.sch]
2014-12-12 Started schematic. Voltage selection circuit added.
    [SparkFun_Interactive_Badge.sch]
2014-12-12 Added LDO to power section in sch
    [SparkFun_Interactive_Badge.sch]
2014-12-13 Finished initial sch. Mock-up layout
    [SparkFun_Interactive_Badge.brd, SparkFun_Interactive_Badge.sch]
2014-12-14 Added PTH UART header on bottom. Added outline of wing on tDocu layer.
    [SparkFun_Interactive_Badge.brd, SparkFun_Interactive_Badge.sch]
2014-12-16 Initial layout complete
    [SparkFun_Interactive_Badge.brd, SparkFun_Interactive_Badge.sch]
2014-12-16 Added mounting holes in brd. Still need to fix 2 air wires.
    [SparkFun_Interactive_Badge.brd]
2014-12-16 Finished layout. Need to move some components to accomodate silk numbers.
    [SparkFun_Interactive_Badge.brd, SparkFun_Interactive_Badge.sch]
2014-12-16 Moved pins. Added silk.
    [SparkFun_Interactive_Badge.brd, SparkFun_Interactive_Badge.sch]
2014-12-16 Added bottom silk. Added A6, A7 silk.
    [SparkFun_Interactive_Badge.brd, SparkFun_Interactive_Badge.sch]
2014-12-16 Colored in silk for required headers.
    [SparkFun_Interactive_Badge.brd, SparkFun_Interactive_Badge.sch]
2014-12-16 Updated frame with name
    [SparkFun_Interactive_Badge.brd, SparkFun_Interactive_Badge.sch]
2014-12-17 Added 4MHz resonator.
    [SparkFun_Interactive_Badge.brd, SparkFun_Interactive_Badge.sch]
2014-12-18 Fixed route out of D2. Added silk for TX and RX on Game Port. Added dimensions.
    [SparkFun_Interactive_Badge.brd]
2014-12-18 Changed 'Badger Stick' to 'BadgerStick' in silk.
    [SparkFun_Interactive_Badge.brd]
2014-12-19 Added badger logo.
    [SparkFun_Interactive_Badge.brd, SparkFun_Interactive_Badge.sch]
2014-12-19 Added half-badger logo.
    [SparkFun_Interactive_Badge.brd]
2014-12-22 Added badge dimensions on custom layer.
    [SparkFun_Interactive_Badge.brd]
2014-12-22 Fixed changes from QC checklist. Made all 'Y' juntions into 'T' junctions. Added PWR and LED silk. Moved dimensions to layer 47. Removed 'values' from headers in sch and brd.
    [SparkFun_Interactive_Badge.brd, SparkFun_Interactive_Badge.sch]
2015-01-22 Updated to v10
    [SoftwareSerial_Baud_Table.ods, SparkFun_Interactive_Badge.brd, SparkFun_Interactive_Badge.sch]
2015-01-22 Removed bridge between pads on Cypress. Removed extraneous measurements outside of board.
    [SparkFun_Interactive_Badge.brd]
2015-01-23 created panel v10
    [SparkFun_Interactive_Badge_Panel_v10.brd]
2015-01-23 Added board definition and bootloader files for the BadgerStick.
2015-02-14 Added win condition checking and animation. Removed production test code and Alpha Station prototype code.
2015-02-19 Lessing delay after successful test
    Delay was 5 seconds. Shortening it to 2 seconds per production feedback.
    [BadgerSX15_Badges.ino]
2015-02-19 Updating Station Firmware
    BadgerSX15_Stations.ino is now the firmware being shipped on ARM's
    station (non-alpha station 0x01)
2015-04-13 More re-routing for v11 of the BadgerStick.
    [SparkFun_Interactive_Badge.brd, SparkFun_Interactive_Badge.sch]
2015-04-13 Replaced battery pins with JST, added inline resistors to FTDI, and changed Game Port pins to hardware UART. Began routing new lines. Not finished. Removed SVG files of layout (outdated).
2015-04-13 Finished new layout with JST, inline resistors (UART), and 0/1 pin game port.
    [SparkFun_Interactive_Badge.brd]
2015-04-14 Adjusted vias to allow for 2 connections to GND from 328p. Moved silk slightly to avoid vias (as possible).
    [SparkFun_Interactive_Badge.brd, SparkFun_Interactive_Badge.sch]
2015-04-20 Changed LED silk to '13'. Added notes to sch about voltage range and JST connector. Moved wire in sch for VCC on 328p to avoid confusion with the RESET line.
    [SparkFun_Interactive_Badge.brd, SparkFun_Interactive_Badge.sch]
2015-04-28 Corrected eagle file names
    Corrected to "BadgerStick"
    [BadgerStick.brd, BadgerStick.sch]
2015-04-28 Changed dimension thickness, added silk to reset button, and removed pour bridge under FTDI.
    [SparkFun_BadgerStick.brd, SparkFun_BadgerStick.sch]
2015-05-28 Moved board definition files to separate badgerstick directory.
2015-08-25 Remvoed flickering in frames. Adjusted number of max actions to 30
2015-08-26 Initial comms working. Stick fails to get full message sometimes.
    [BadgerNMMF15_Badges.ino, BadgerNMMF15_StationTest.ino, BadgerSX15_Badges.ino]
2015-09-10 Updated boards.txt with variant variable
2016-01-18 Updated boards.txt to work with arduino 1.6.6 and 1.6.7
2016-02-16 Switched Cypress USB-Serial bridge to FT232RL
    [SparkFun_BadgerStick.brd, SparkFun_BadgerStick.sch]
2016-03-02 Fixing directory names, adding license file, updating README with tutorial links
    [SoftwareSerial_Baud_Table.ods, SparkFun_Interactive_Badge_Panel_v10.brd]
2016-03-02 Adding changed directories
    [SoftwareSerial_Baud_Table.ods, SparkFun_Interactive_Badge_Panel_v10.brd]

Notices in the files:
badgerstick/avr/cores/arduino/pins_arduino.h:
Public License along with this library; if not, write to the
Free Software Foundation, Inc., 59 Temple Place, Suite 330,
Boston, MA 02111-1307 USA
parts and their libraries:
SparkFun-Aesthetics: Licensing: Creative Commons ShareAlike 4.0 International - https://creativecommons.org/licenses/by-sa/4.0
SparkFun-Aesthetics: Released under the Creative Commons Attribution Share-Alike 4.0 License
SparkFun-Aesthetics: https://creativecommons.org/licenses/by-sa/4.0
